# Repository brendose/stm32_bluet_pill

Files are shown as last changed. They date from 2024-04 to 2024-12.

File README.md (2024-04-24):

<h1 align="center">Welcome to Project: stm32_bluet_pill </br> (a Bluetooth OSHW design) </h1>
<div align="center">

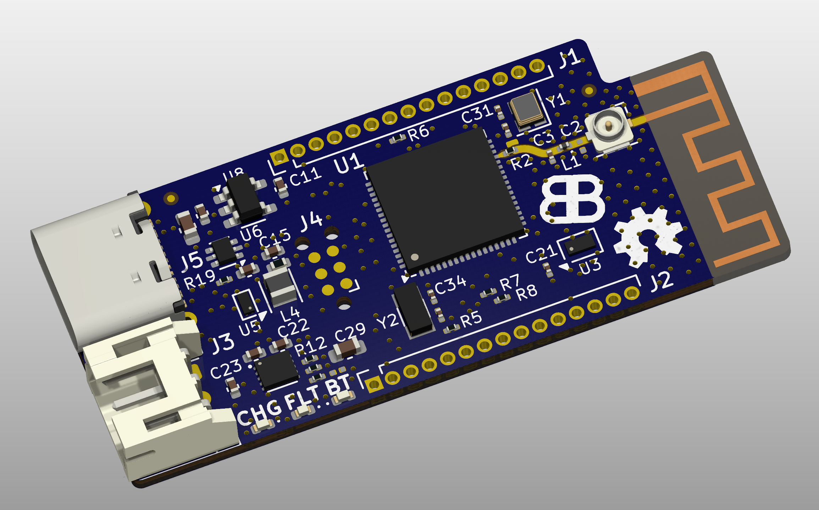
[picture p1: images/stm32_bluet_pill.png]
   

<a href="#introduction">Introduction</a> &nbsp;&bull;&nbsp;
<a href="#directory">Directory</a> &nbsp;&bull;&nbsp;
<a href="#documentation">Documentation</a> &nbsp;&bull;&nbsp;
<a href="#notes">Notes</a>
</div>

# Introduction
The <b>stm32_bluet_pill</b> project is a 'breadboardable' 1.8V IO STM32WB55 Bluetooth Module with battery charging. 
The purpose of this project is to provide a development platform for wearables. The board contains:

- ST Microelectronics STM32WB55
- 32Mbit QSPI Flash
- Texas Instruments BQ25185 battery charger
- PCB Antenna with U.FL switch connector 
- 2x 15 pin GPIO headers
- Tag-Connect JTAG connector 
- USB-C connector
- 3-Pin Battery connector
- Charge Status and Bluetooth Connection indicator LEDs

## Directory

### Projects top-level directory

    .
    ├── bom                     # stm32_blue_pill iBOM
    ├── docs                    # Documentation files (alternatively `doc`)
    ├── images                  # Images used on this GitHub page
    ├── schematics              # Schematics of the stm32_bluet_pill
    ├── step                    # 3D STEP model of the design
    ├── tapeout                 # Gerbers, Drill Drawings and other output files for PCB Fab and Assembly
    └── README.md

## Documentation

### Block Diagram
<div align="center">
  
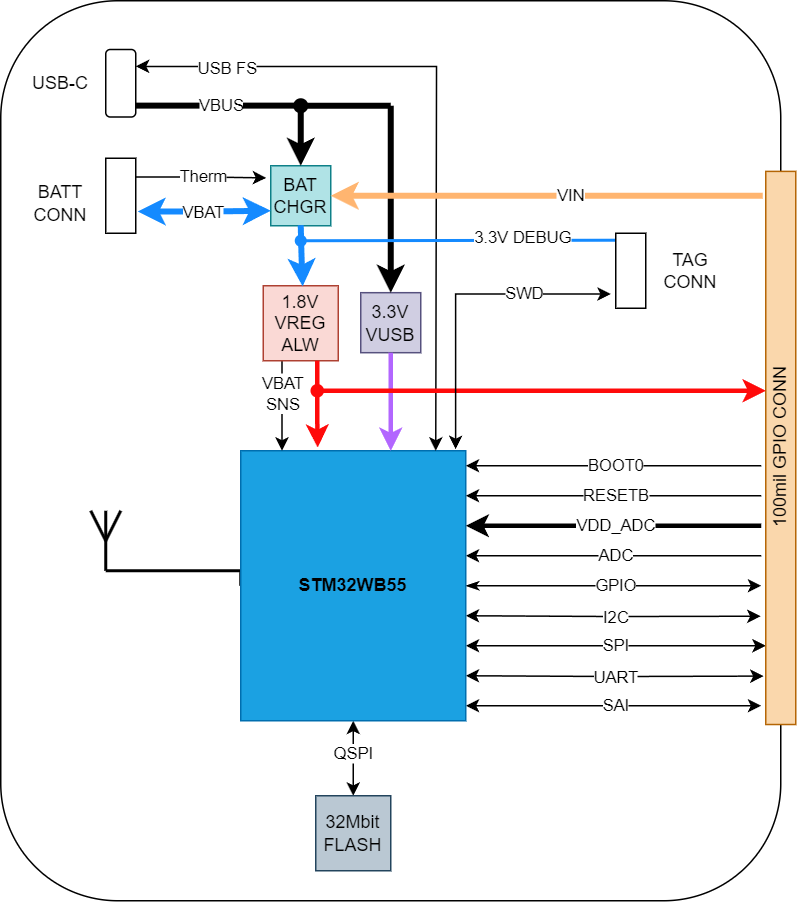
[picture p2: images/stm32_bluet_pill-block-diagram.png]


</div>

## Notes

This repository is not actively maintained, so if you spot any bugs, please <a href="https://github.com/brendose/stm32_bluet_pill/issues/new">raise an issue</a> and I will try get to it.

This is not an officially supported Google product.

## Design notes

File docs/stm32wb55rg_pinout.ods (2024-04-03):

Pin Number | Pin Name | Function | Notes
1 | VBAT
2 | PC13 | RTC_TAMP1/RTC_TS/ RTC_OUT/WKUP2
3 | PC14 | OSC32_IN
4 | PC15 | OSC32_OUT
5 | BOOT0
6 | PB8 | QUADSPI_BK1_IO1
7 | PB9 | QUADSPI_BK1_IO0
8 | NRST | RESETB
9 | PC0 | I2C3_SCL
10 | PC1 | I2C3_SDA
11 | PC2 | ADC1_IN3
12 | PC3 | ADC1_IN4
13 | VREF+
14 | VDDA
15 | PA0 | ADC1_IN5
16 | PA1 | QUADSPI_BK1_NCS
17 | PA2 | LPUART_TX
18 | PA3 | QUADSPI_CLK
19 | PA4 | VIN_SNS_ADC1_IN9
20 | PA5
21 | PA6 | QUADSPI_BK1_IO3
22 | PA7 | QUADSPI_BK1_IO2
23 | PA8 | SAI1_SCK_A
24 | PA9 | SAI1_FS_A
25 | PC4
26 | PC5
27 | PB2
28 | PB10 | LPUART_RX
29 | PB11
30 | VDDA
31 | RF1
32 | VSSRF
33 | VDDRF
34 | OSC_OUT
35 | OSC_IN
36 | AT0 | NU
37 | AT1 | NU
38 | PB0
39 | PB1
40 | PE4
41 | VFBSMPS
42 | VSSSMPS
43 | VLXSMPS
44 | VDDSMPS
45 | VDD
46 | PB12 | SPI2_NSS
47 | PB13 | SPI2_SCK
48 | PB14 | SPI2_MISO
49 | PB15 | SPI2_MOSI
50 | PC6 | SPI2_DEV_DC
51 | PA10 | SAI1_SD_A
52 | PA11 | USB_D_N
53 | PA12 | USB_D_P
54 | PA13 | SWDIO
55 | VDDUSB
56 | PA14 | SWCLK
57 | PA15
58 | PC10
59 | PC11
60 | PC12 | RTC_TAMP3/WKUP3
61 | PD0
62 | PD1
63 | PB3 | CHG_LED_GRN
64 | PB4 | CHG_LED_RED
65 | PB5 | BT_CONN_LED
66 | PB6
67 | PB7
68 | VDD

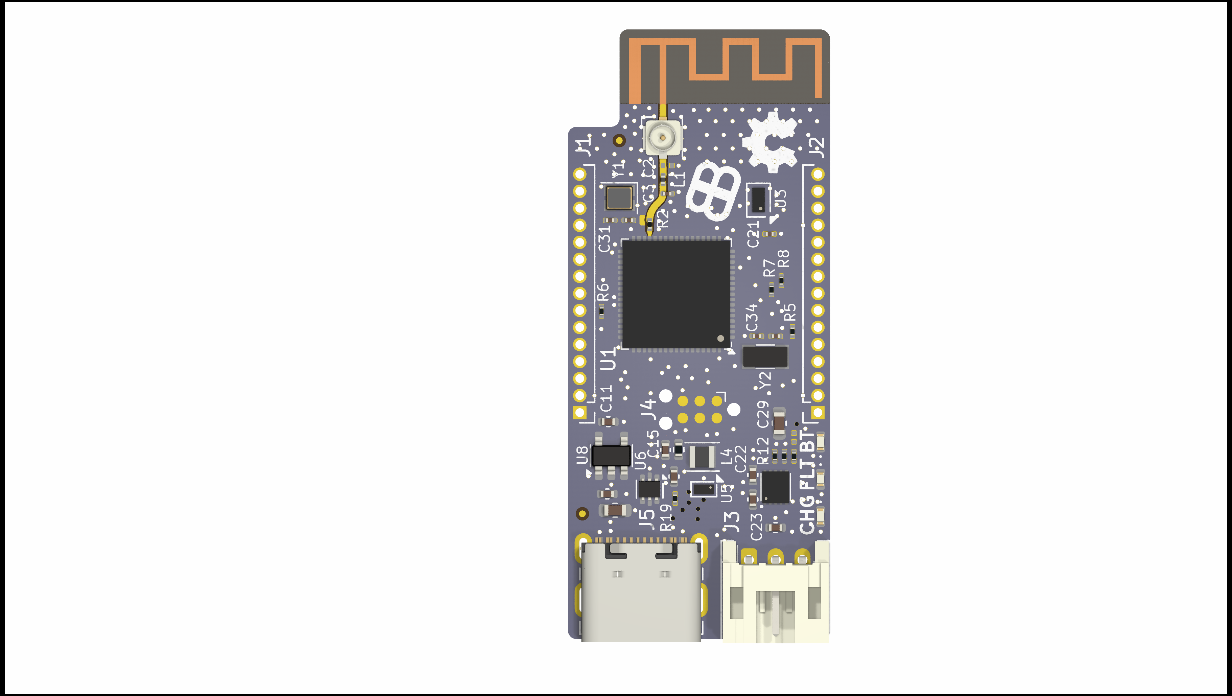
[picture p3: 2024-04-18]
images/stm32_bluet_pill_front.png

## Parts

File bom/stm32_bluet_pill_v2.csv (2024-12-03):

Reference | Value | Datasheet | Footprint | Qty | DNP
AE1 | PCB MIFA | https://www.ti.com/lit/an/swra117d/swra117d.pdf?ts=1713312109091 | RF_Antenna:Texas_SWRA117D_2.4GHz_Right | 1
C1 | 10N | ~ | Capacitor_SMD:C_0201_0603Metric | 1
C2 | 0.7P | ~ | Capacitor_SMD:C_0201_0603Metric | 1 | DNP
C3 | 0.7P | ~ | Capacitor_SMD:C_0201_0603Metric | 1
C4,C5,C6,C7,C8,C9,C10,C13,C17,C19,C21,C25,C28,C30 | 100N | ~ | Capacitor_SMD:C_0201_0603Metric | 14
C11,C12,C15 | 4.7U | ~ | Capacitor_SMD:C_0402_1005Metric | 3
C14 | 100P | ~ | Capacitor_SMD:C_0201_0603Metric | 1
C16,C22,C33 | 1.0U | ~ | -- mixed values -- | 3
C18,C34 | 7P | ~ | Capacitor_SMD:C_0201_0603Metric | 2
C20 | 2.2U 35V | ~ | Capacitor_SMD:C_0603_1608Metric | 1
C23,C29 | 1.0U 35V | ~ | -- mixed values -- | 2
C24 | 10U 10V | ~ | Capacitor_SMD:C_0402_1005Metric | 1
C26 | 10U | ~ | Capacitor_SMD:C_0402_1005Metric | 1
C27 | 1.0U 16V | ~ | Capacitor_SMD:C_0402_1005Metric | 1
C31,C32 | 8P | ~ | Capacitor_SMD:C_0201_0603Metric | 2
D1,D4,D5 | LED | ~ | Diode_SMD:D_0402_1005Metric | 3
D2 | RB081LAM-20TR | https://fscdn.rohm.com/en/products/databook/datasheet/discrete/diode/schottky_barrier/rb081lam-20tr-e.pdf | Diode_SMD:D_SOD-128 | 1
D3 | VSKY05301006-G4-08 | ~ | Diode_SMD:D_0402_1005Metric | 1
J3 | PH_S3B-PH-K | https://www.jst-mfg.com/product/pdf/eng/eZH.pdf | Connector_JST:JST_PH_S3B-PH-K_1x03_P2.00mm_Horizontal | 1
J5 | DX07S016JA1R1500 |  | Connector_USB:USB_C_Receptacle_JAE_DX07S016JA1R1500 | 1
L1 | 2.2N | ~ | Diode_SMD:D_0201_0603Metric | 1
L4 | 2.2U | ~ | Inductor_SMD:L_Murata_DFE201610P | 1
Q1,Q2 | DMG1012T | https://www.diodes.com/assets/Datasheets/ds31783.pdf | Package_TO_SOT_SMD:SOT-523 | 2
R1,R19,R25 | 100K | ~ | Resistor_SMD:R_0201_0603Metric | 3
R2,R10,R14,R23,R26 | 0R | ~ | -- mixed values -- | 5
R3,R22 | 470R | ~ | Resistor_SMD:R_0201_0603Metric | 2
R4,R5,R17 | 10K | ~ | Resistor_SMD:R_0201_0603Metric | 3
R6,R9,R13,R15 | 0R | ~ | -- mixed values -- | 4 | DNP
R7,R8 | 680R | ~ | Resistor_SMD:R_0201_0603Metric | 2
R11 | 2.4K | ~ | Resistor_SMD:R_0201_0603Metric | 1
R12 | 600R | ~ | Resistor_SMD:R_0201_0603Metric | 1
R16 | 2.2K | ~ | Resistor_SMD:R_0201_0603Metric | 1
R18,R24 | 1K | ~ | Resistor_SMD:R_0201_0603Metric | 2
R20,R21 | 5.1K | ~ | Resistor_SMD:R_0201_0603Metric | 2
TP1 | MS-156C3 | https://www.hirose.com/en/product/document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 | Connector_Coaxial:CoaxialSwitch_Hirose_MS-156C3_Horizontal | 1
U1 | STM32WB55RGVx | https://www.st.com/resource/en/datasheet/stm32wb55rg.pdf | Package_DFN_QFN:QFN-68-1EP_8x8mm_P0.4mm_EP6.4x6.4mm | 1
U3 | AT25SL321-U | https://www.adestotech.com/wp-content/uploads/AT25SL321_112.pdf | Package_CSP:WLCSP-8_1.551x2.284mm_P0.5mm | 1
U4 | BQ25185 | https://www.ti.com/lit/ds/symlink/bq25185.pdf?ts=1709530829257 | user_wson:Texas_DLH_WSON-10 | 1
U5 | TPS62746 | https://www.ti.com/lit/ds/symlink/tps62746.pdf?ts=1709244779633 | Package_BGA:Texas_DSBGA-8_0.705x1.468mm_Layout2x4_P0.4mm | 1
U6 | USBLC6-2P6 | https://www.st.com/resource/en/datasheet/usblc6-2.pdf | Package_TO_SOT_SMD:SOT-666 | 1
U8 | TPS7A0533PDBV | https://www.ti.com/lit/ds/symlink/tps7a05.pdf | Package_TO_SOT_SMD:SOT-23-5 | 1
Y1 | ECS-320-8-37CKM | https://ecsxtal.com/store/pdf/ecx-1637.pdf | Crystal:Crystal_SMD_2016-4Pin_2.0x1.6mm | 1
Y2 | SC32S-7PF20PPM | ~ | Crystal:Crystal_SMD_3215-2Pin_3.2x1.5mm | 1

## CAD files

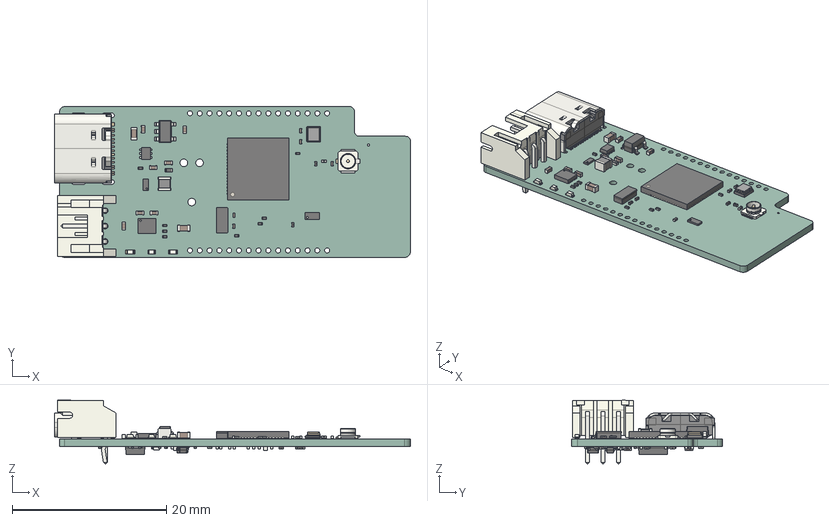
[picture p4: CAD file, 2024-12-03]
step/stm32_bluet_pill.step
46.1 x 19.6 x 8.25 mm
R_0201_0603Metric x 20
C_0201_0603Metric x 23
C_0402_1005Metric x 9
CQ assembly x 3
C_0603_1608Metric x 2
LED_0402_1005Metric x 3
L_0201_0603Metric
L_0805_2012Metric
R_0402_1005Metric
JST_S3B_PH_K
USB_C_Receptacle_16P_TopMnt_Horizontal_GCT_USB4105-xx-A
Crystal_SMD_2520-4Pin_2.5x2.0mm
U.FL_Hirose_U.FL-R-SMT-1_Vertical
MicroCrystal_CC7V_T1A
SOT_666
SOT_23_5
QFN_68_1EP_8x8mm_P04mm_EP52x52mm
SOT_323_SC_70 x 2
R_0603_1608Metric
D_SOD-128
stm32_bluet_pill_PCB

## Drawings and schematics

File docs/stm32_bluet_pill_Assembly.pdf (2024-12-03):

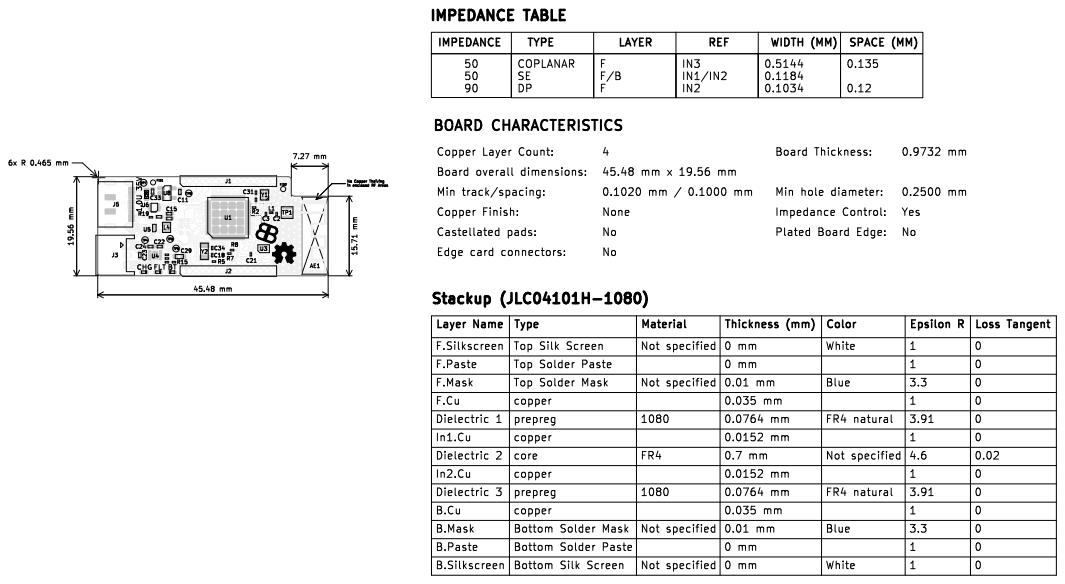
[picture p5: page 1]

Top Solder Mask F.Paste BOARD CHARACTERISTICS

1080 Copper Layer Count: Bottom Silk Screen

Layer Name | pads: F.Cu | | | | | | | 0 Top Solder Paste Castellated
1 FR4 F.Mask 3.3 White | | 0 Edge card connectors: 0

copper | | 0 mm (mm) 0.035 mm | | 1 White 3.91 Not specified B.Mask 3.91 | | 0 Thickness 0
1 | Top Silk copper F.Silkscreen | Screen | | | | | 0.01 mm | | 1 Dielectric

Not specified | 0.0764 mm | | | | 0.02 B.Paste

core | | | | 4.6

prepreg | | | | | 0
copper | | 0.035 mm | | | | 0

Paste | | 0 mm | | | | 0 Bottom Solder

B.Silkscreen

Id: 1/1 Title: stm32_bluet_pill File: stm32_bluet_pill.kicad_pcb Sheet: Black And White TOP Brendan Bleker Designed by:

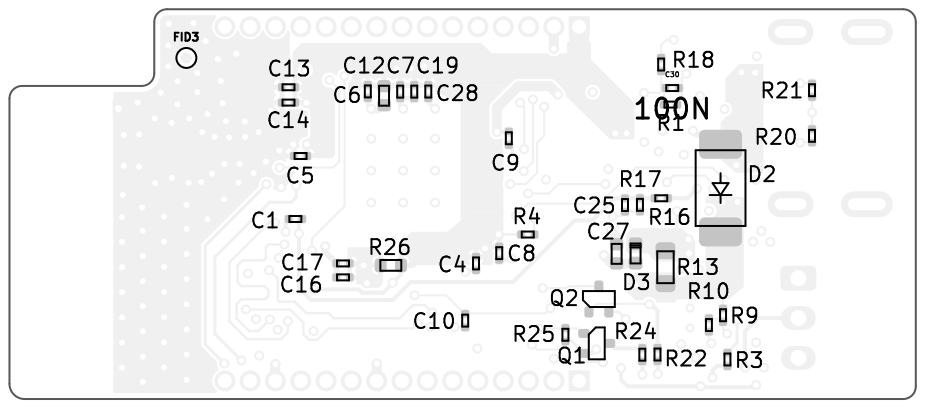
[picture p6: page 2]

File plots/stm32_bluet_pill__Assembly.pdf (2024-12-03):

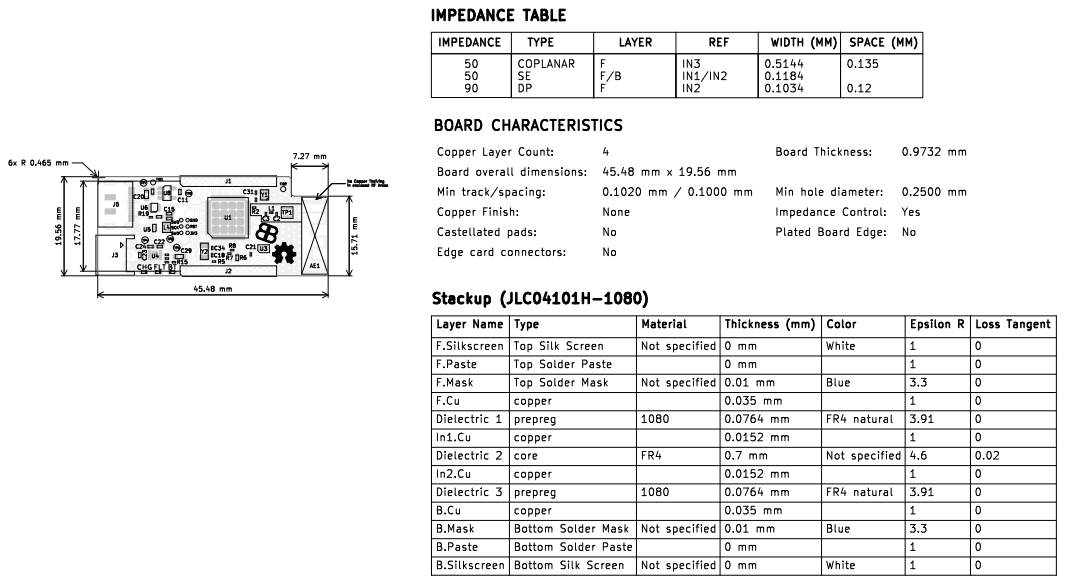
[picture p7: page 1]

Top Solder Mask F.Paste BOARD CHARACTERISTICS

1080 Copper Layer Count: Bottom Silk Screen

Layer Name | pads: F.Cu | | | | | 0 Top Solder Paste Castellated
1 FR4 F.Mask 3.3 White | 0 Edge card connectors: 0

copper | | 0 mm (mm) 0.035 mm | | 1 White 3.91 Not specified B.Mask 3.91 | | 0 Thickness 0
1 | Top Silk copper F.Silkscreen Screen | | | | 0.01 mm | | 1 Dielectric

prepreg | Not specified | 0.0764 mm | | | 0.02 B.Paste

core | | | | 4.6

In2.Cu | | | 0.0152 mm
Dielectric 3 | prepreg | | | | | | 0

copper | | 0.035 mm | | | | 0
Bottom Solder Mask | Not specified | 0.01 mm | | | | 0
Paste | | 0 mm | | 1 | 0 Bottom Solder

B.Silkscreen

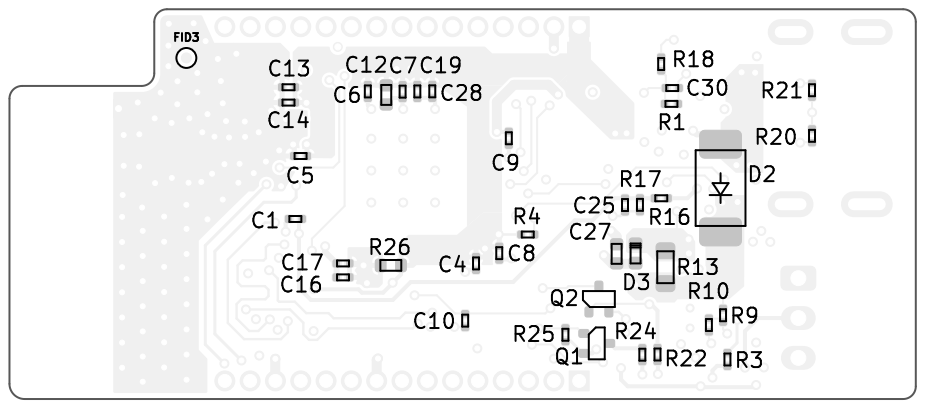
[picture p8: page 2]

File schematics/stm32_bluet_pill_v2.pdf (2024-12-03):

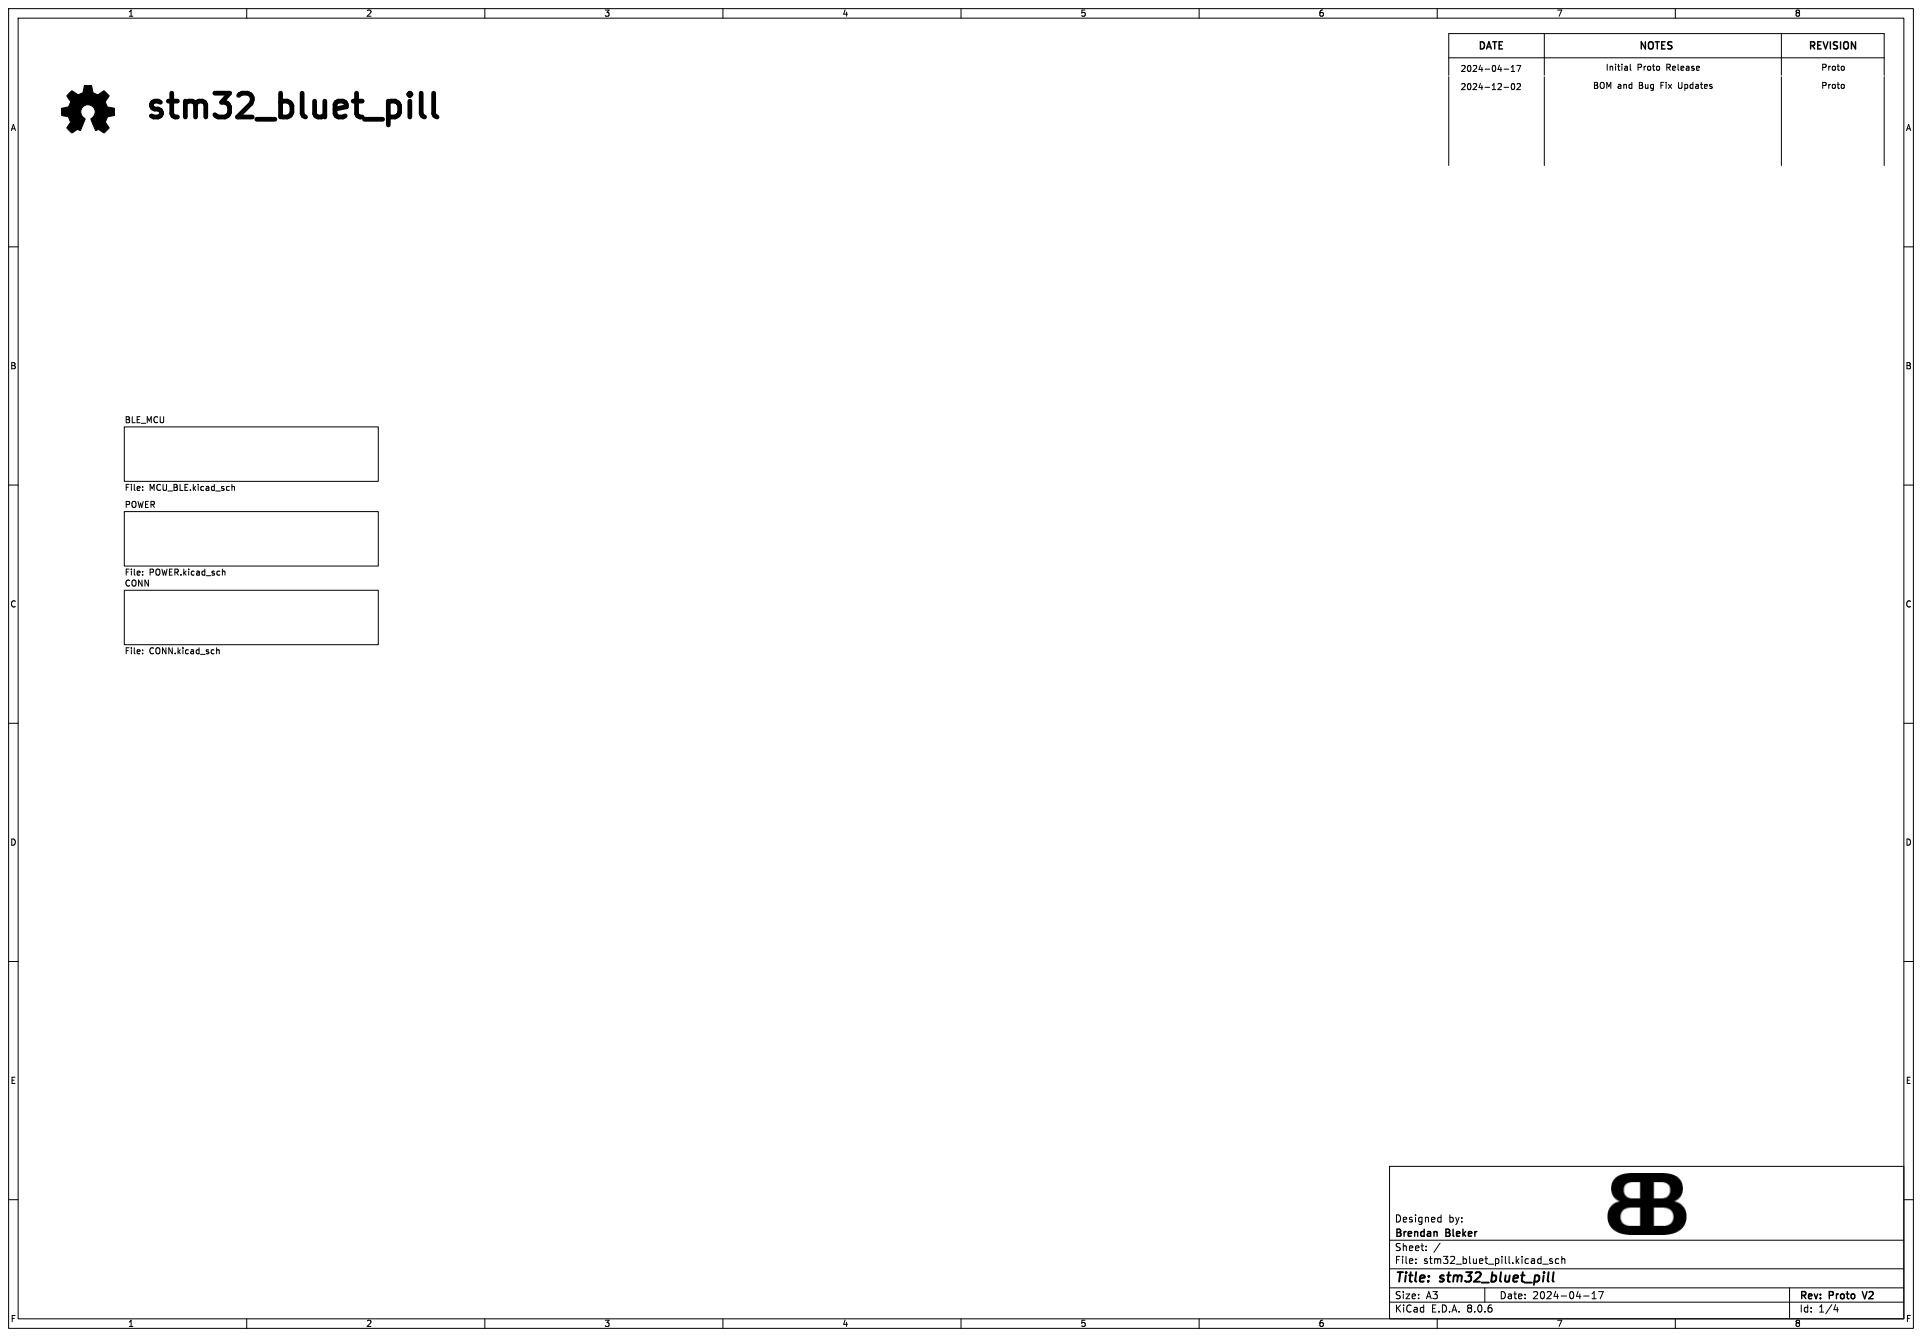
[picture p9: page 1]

Initial Proto Release | Proto BOM and Bug Fix Updates Proto

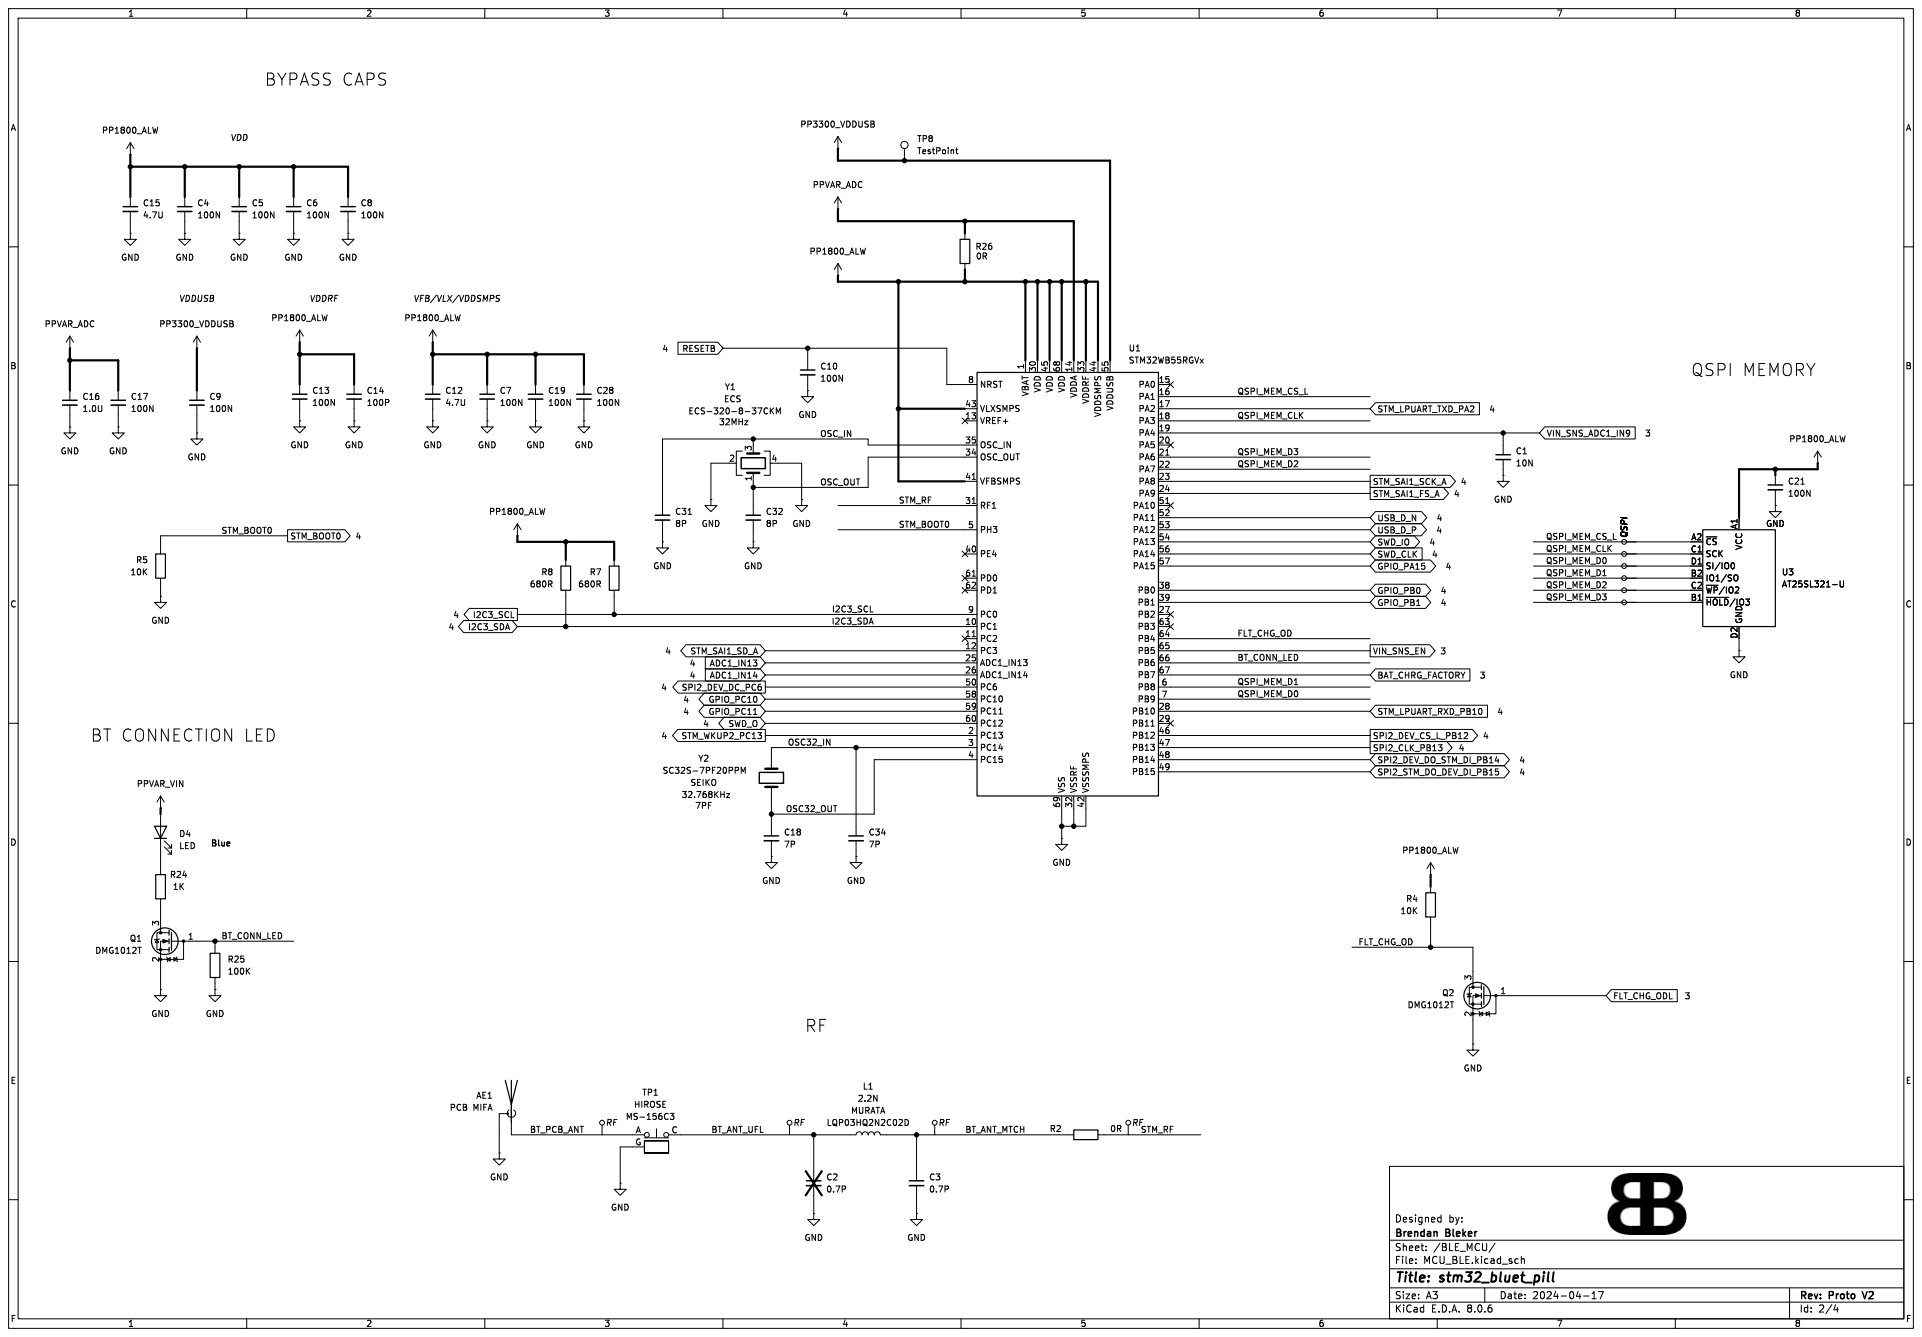
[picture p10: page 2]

VFB/VLX/VDDSMPS BYPASS CAPS

1 PC1 10 PC2 11 PC3 12 VREF+ 13 VDDA 14 PA0 15 PA1 16 PA2 17 PA3 18 PA4 19 PC13 2 PA5 20 PA6 21 PA7 22 PA8 23 PA9 24 ADC1_IN13 25 ADC1_IN14 26 PB2 27 PB10 28 PB11 29 PC14 3 VDD 30 RF1 31 VSSRF 32 VDDRF 33 OSC_OUT 34 OSC_IN 35 PB0 38 PB1 39 PC15 4 PE4 40 VFBSMPS 41 VSSSMPS 42 VLXSMPS 43 VDDSMPS 44 VDD 45 PB12 46 PB13 47 PB14 48 PB15 49 PH3 5 PC6 50 PA10 51 PA11 52 PA12 53 PA13 54 VDDUSB 55 PA14 56 PA15 57 PC10 58 PC11 59 PB8 6 PC12 60 PD0 61 PD1 62 PB3 63 PB4 64 PB5 65 PB6 66 PB7 67 VDD 68 VSS 69 PB9 7 NRST 8 PC0 9 U1STM32WB55RGVx R26

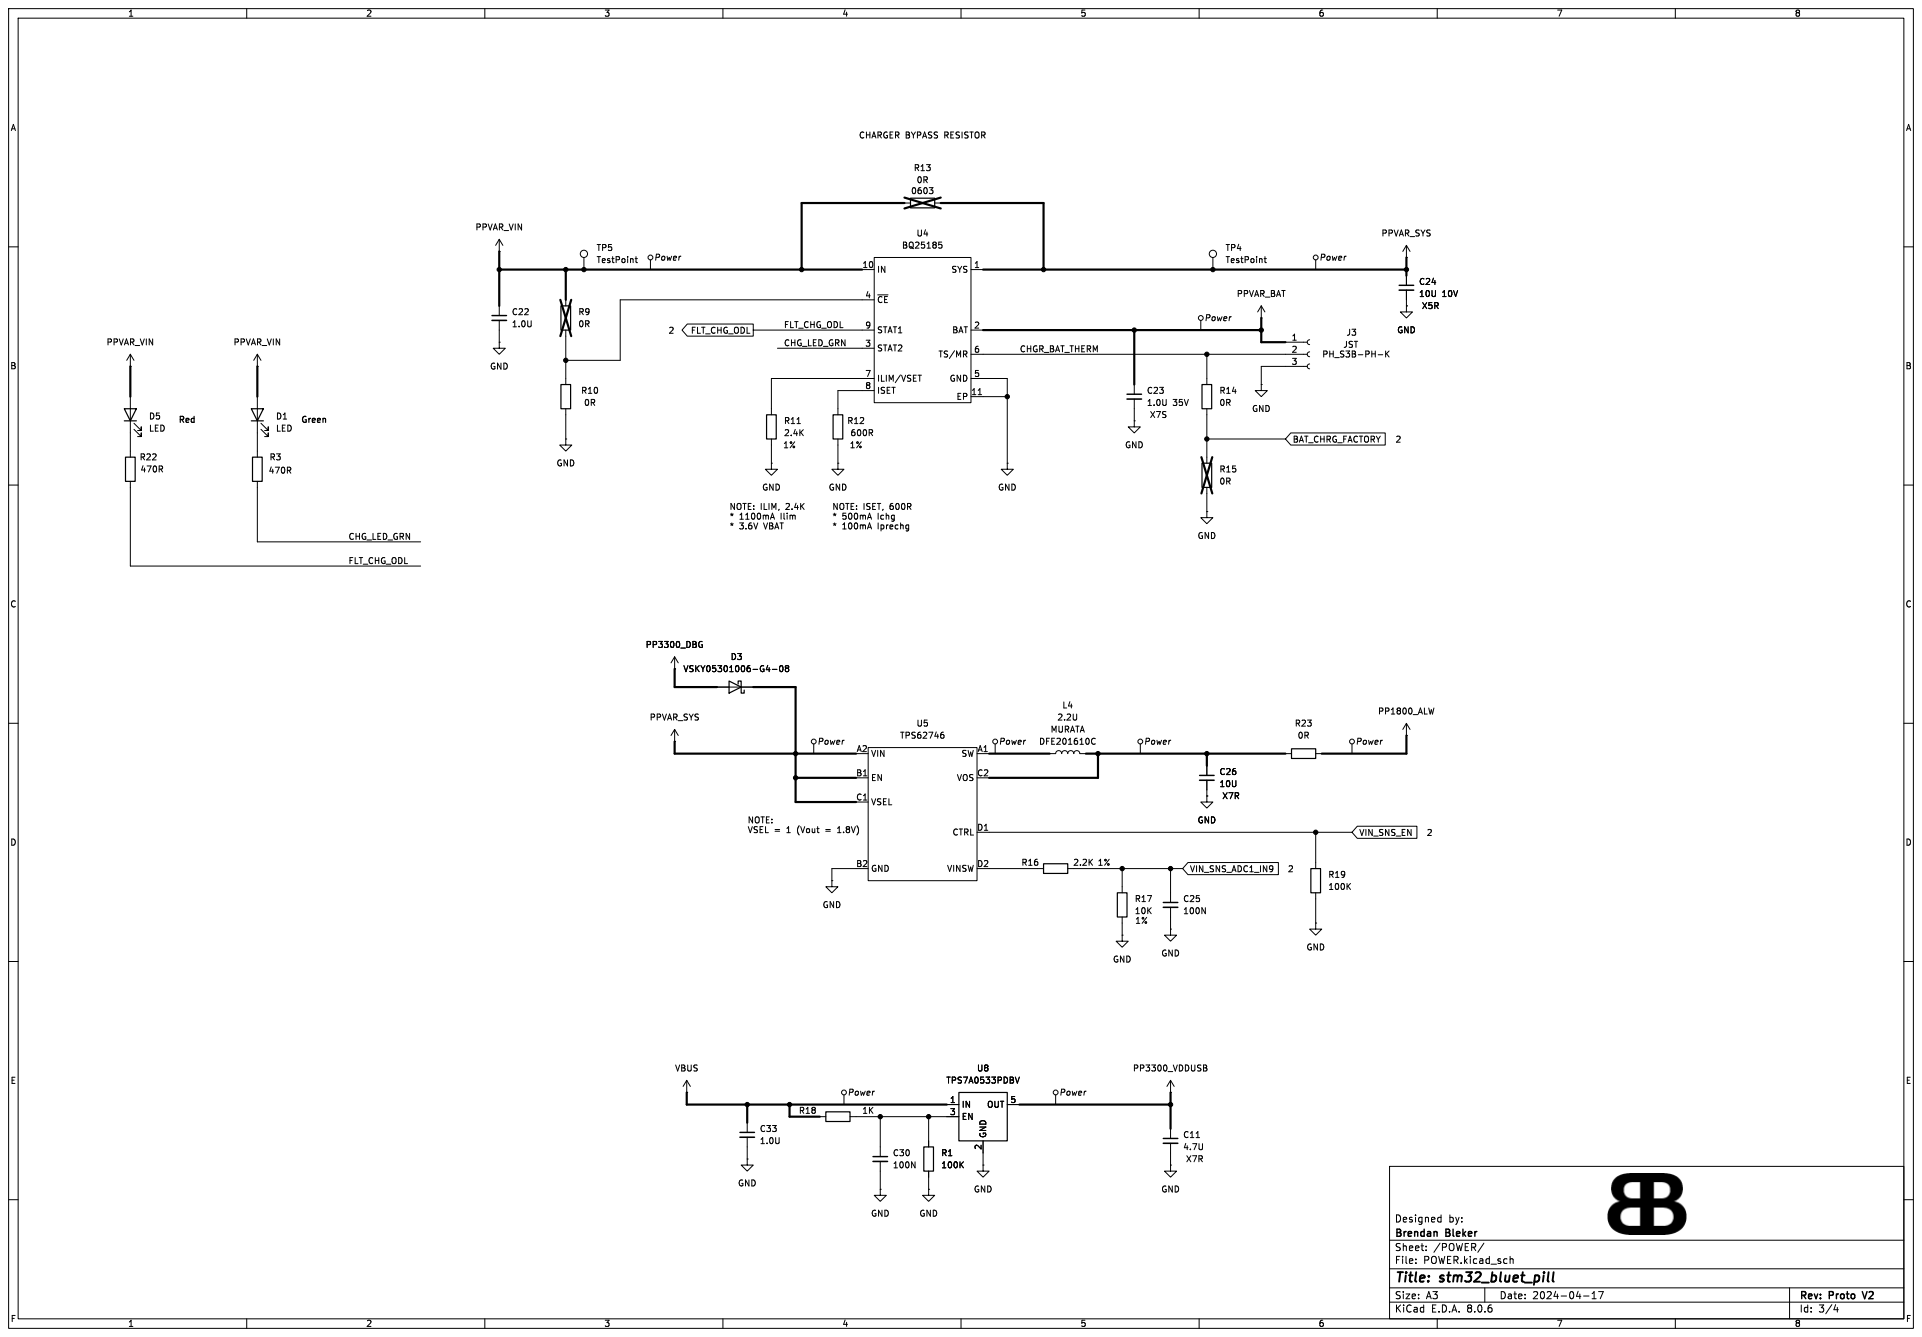
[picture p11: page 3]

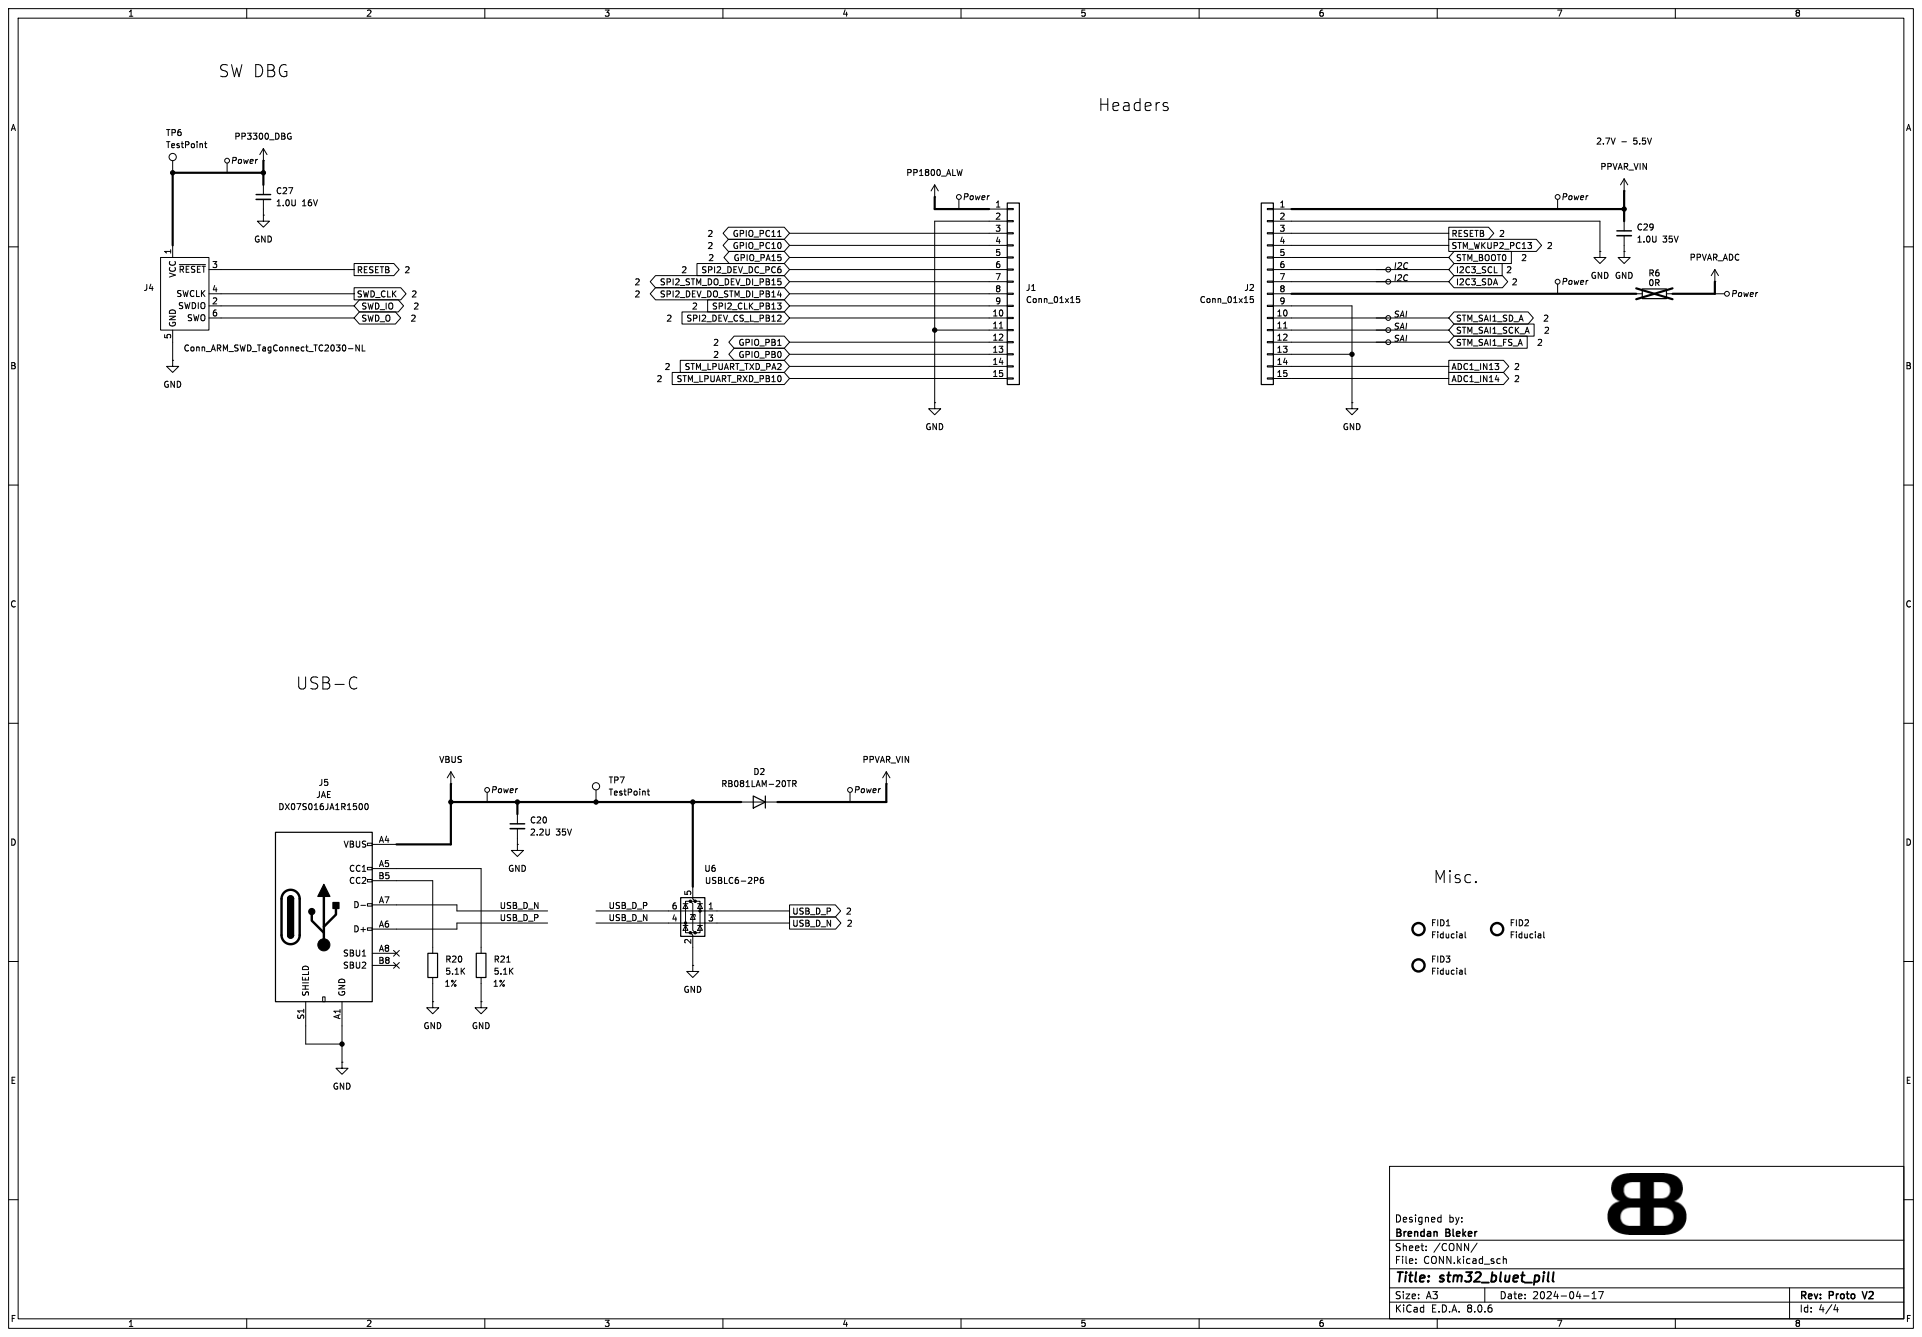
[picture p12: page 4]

1 SWDIO 2 ~{RESET}3 SWCLK 4 GND
2.2U 35V GNDVCC

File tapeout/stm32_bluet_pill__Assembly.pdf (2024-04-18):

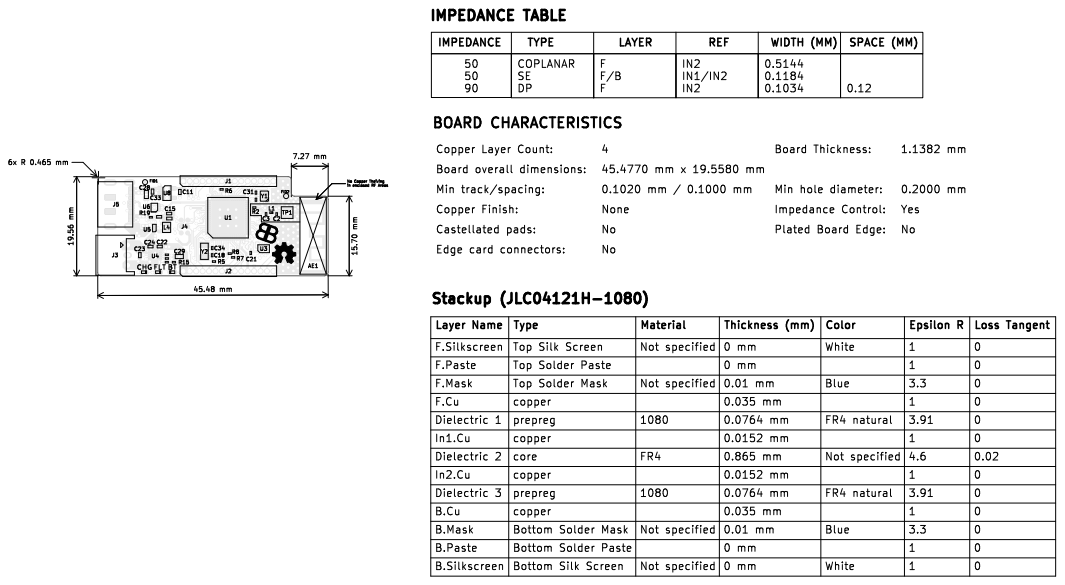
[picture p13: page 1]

IMPEDANCE TABLE
prepreg Min track/spacing: F.Cu

Layer Name | | | | | | | | | 1 No
0.0152 mm 0.01 mm | 3.91 Material | Loss Tangent 0

F.Paste | | | | | FR4 | | | Epsilon R

0.01 mm 0.035 mm | White | | 0

copper | | 0 mm 0.0764 mm

1 In1.Cu | | | Not specified | | | 1 Blue Dielectric | 0 Bottom Solder Mask 0

In2.Cu | | | | 0.0152 mm | Not specified | 3.91 B.Silkscreen | 0 White 0 B.Mask

core | | | 0.865 mm | | 4.6

0 mm | | | 0
0 mm | | | | 0

Id: 1/1 Title: stm32_bluet_pill File: stm32_bluet_pill.kicad_pcb Sheet: Brendan Bleker Designed by:

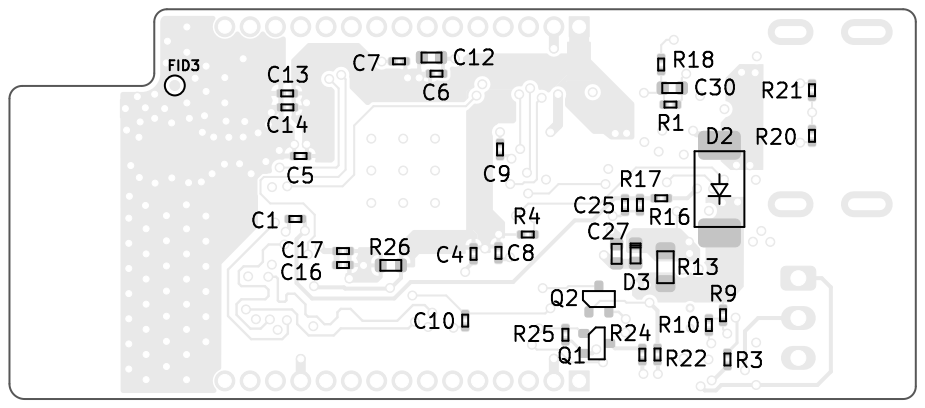
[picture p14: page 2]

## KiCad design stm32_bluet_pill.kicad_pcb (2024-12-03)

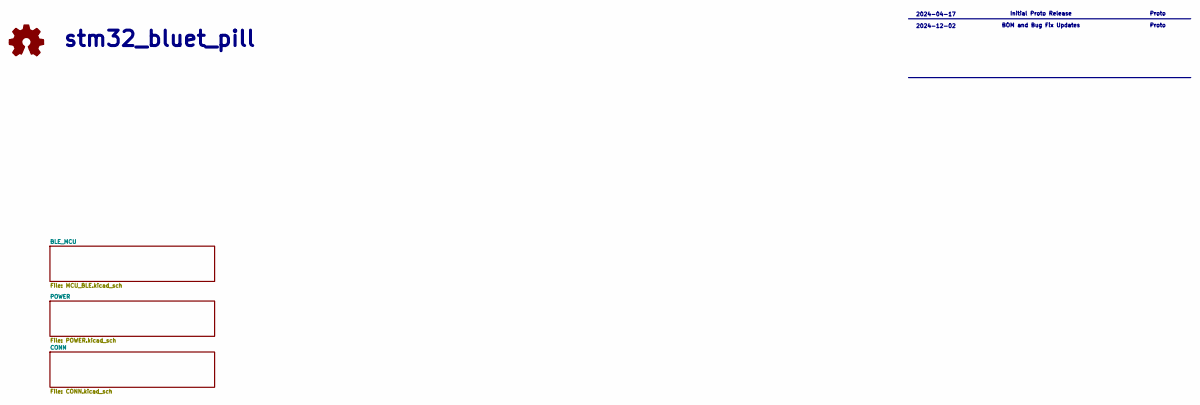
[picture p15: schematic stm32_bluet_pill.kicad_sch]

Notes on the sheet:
Proto
2024-04-17
${TITLE}
Initial Proto Release
BOM and Bug Fix Updates
2024-12-02

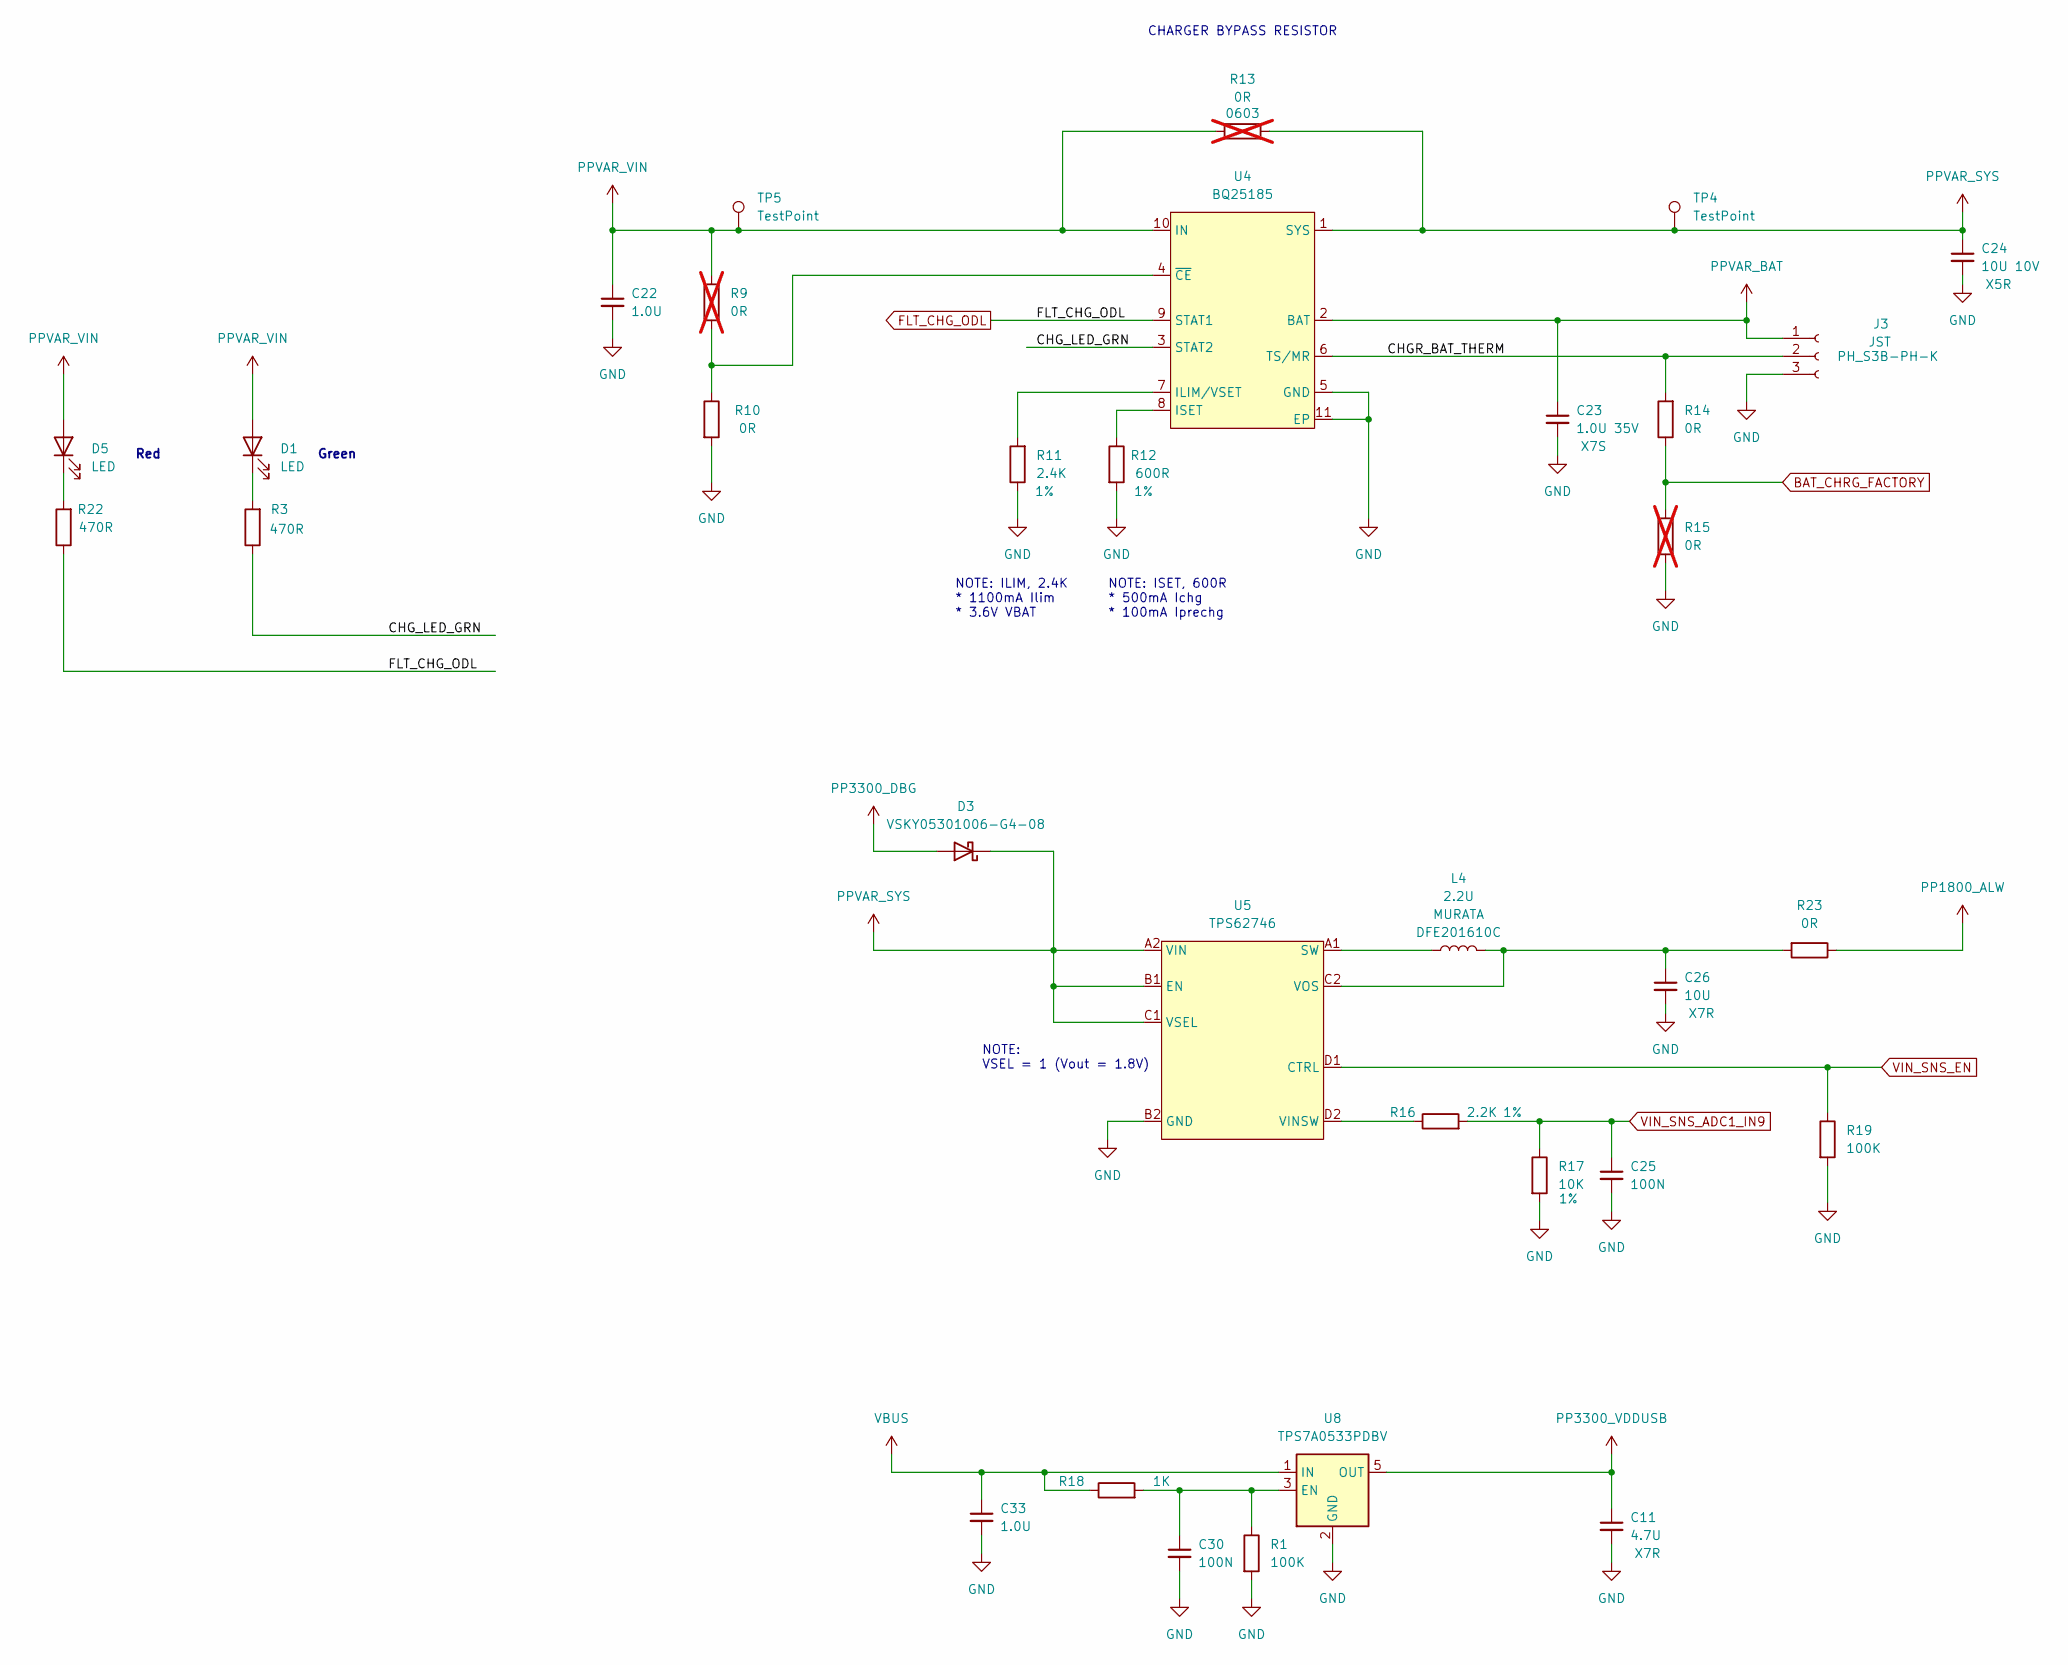
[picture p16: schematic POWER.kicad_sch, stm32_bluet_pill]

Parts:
C11: 4.7U; C_0402_1005Metric; MFG_PN GRM155R60J106ME11
C22, C33: 1.0U; C_0402_1005Metric
C23: 1.0U 35V; C_0402_1005Metric; MFR_PN C1005JB1V105K050BC
C24: 10U 10V; C_0402_1005Metric; MFR_PN CL05A106MP8NUB8
C25, C30: 100N; C_0201_0603Metric
C26: 10U; C_0402_1005Metric; MFG_PN GRM155R60J106ME11
D1, D5: LED; D_0402_1005Metric
D3: VSKY05301006-G4-08; D_0402_1005Metric
J3: PH_S3B-PH-K; JST_PH_S3B-PH-K_1x03_P2.00mm_Horizontal; MFG_PN PH_S3B-PH-K
L4: 2.2U; L_Murata_DFE201610P; MFG_PN DFE201610C
R1, R19: 100K; R_0201_0603Metric
R3, R22: 470R; R_0201_0603Metric
R9, R15: 0R; R_0201_0603Metric; not fitted
R10, R14: 0R; R_0201_0603Metric
R11: 2.4K; R_0201_0603Metric
R12: 600R; R_0201_0603Metric
R13: 0R; R_0603_1608Metric; not fitted
R16: 2.2K; R_0201_0603Metric
R17: 10K; R_0201_0603Metric
R18: 1K; R_0201_0603Metric
R23: 0R; R_0402_1005Metric
TP4, TP5: TestPoint; TestPoint_Pad_D1.0mm
U4: BQ25185; Texas_DLH_WSON-10
U5: TPS62746; Texas_DSBGA-8_0.705x1.468mm_Layout2x4_P0.4mm
U8: TPS7A0533PDBV; SOT-23-5

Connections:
/POWER/CHGR_BAT_THERM: J3.2, R14.2, U4.6 (TS/MR)
/POWER/CHG_LED_GRN: R3.1, U4.3 (STAT2)
BAT_CHRG_FACTORY: R14.1, R15.2; also elsewhere on the board
FLT_CHG_ODL: R22.1, U4.9 (STAT1); also elsewhere on the board
GND: C11.2, C22.2, C23.2, C24.2, C25.2, C26.2, C30.2, C33.2, J3.3, R1.2, R10.2, R11.1, R12.2, R15.1, R17.2, R19.2, U4.5 (GND), U4.11 (EP), U5.B2 (GND), U8.2 (GND); also elsewhere on the board
unnamed: D1.1 (K), R3.2
unnamed: D5.1 (K), R22.2
unnamed: R11.2, U4.7 (ILIM/VSET)
unnamed: R12.1, U4.8 (ISET)
unnamed: R9.1, R10.1, U4.4 (~CE)
unnamed: L4.1, U5.A1 (SW)
unnamed: R16.1, U5.D2 (VINSW)
unnamed: C26.1, L4.2, R23.2, U5.C2 (VOS)
unnamed: C30.1, R1.1, R18.2, U8.3 (EN)
PP1800_ALW: R23.1; also elsewhere on the board
PP3300_DBG: D3.2 (A); also elsewhere on the board
PP3300_VDDUSB: C11.1, U8.5 (OUT); also elsewhere on the board
PPVAR_BAT: C23.1, J3.1, U4.2 (BAT)
PPVAR_SYS: C24.1, D3.1 (K), R13.1, TP4.1, U4.1 (SYS), U5.A2 (VIN), U5.B1 (EN), U5.C1 (VSEL)
PPVAR_VIN: C22.1, D1.2 (A), D5.2 (A), R9.2, R13.2, TP5.1, U4.10 (IN); also elsewhere on the board
VBUS: C33.1, R18.1, U8.1 (IN); also elsewhere on the board
VIN_SNS_ADC1_IN9: C25.1, R16.2, R17.1; also elsewhere on the board
VIN_SNS_EN: R19.1, U5.D1 (CTRL); also elsewhere on the board

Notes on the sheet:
CHARGER BYPASS RESISTOR
NOTE: ILIM, 2.4K * 1100mA Ilim * 3.6V VBAT
NOTE: VSEL = 1 (Vout = 1.8V)
Red
NOTE: ISET, 600R * 500mA Ichg * 100mA Iprechg
Green

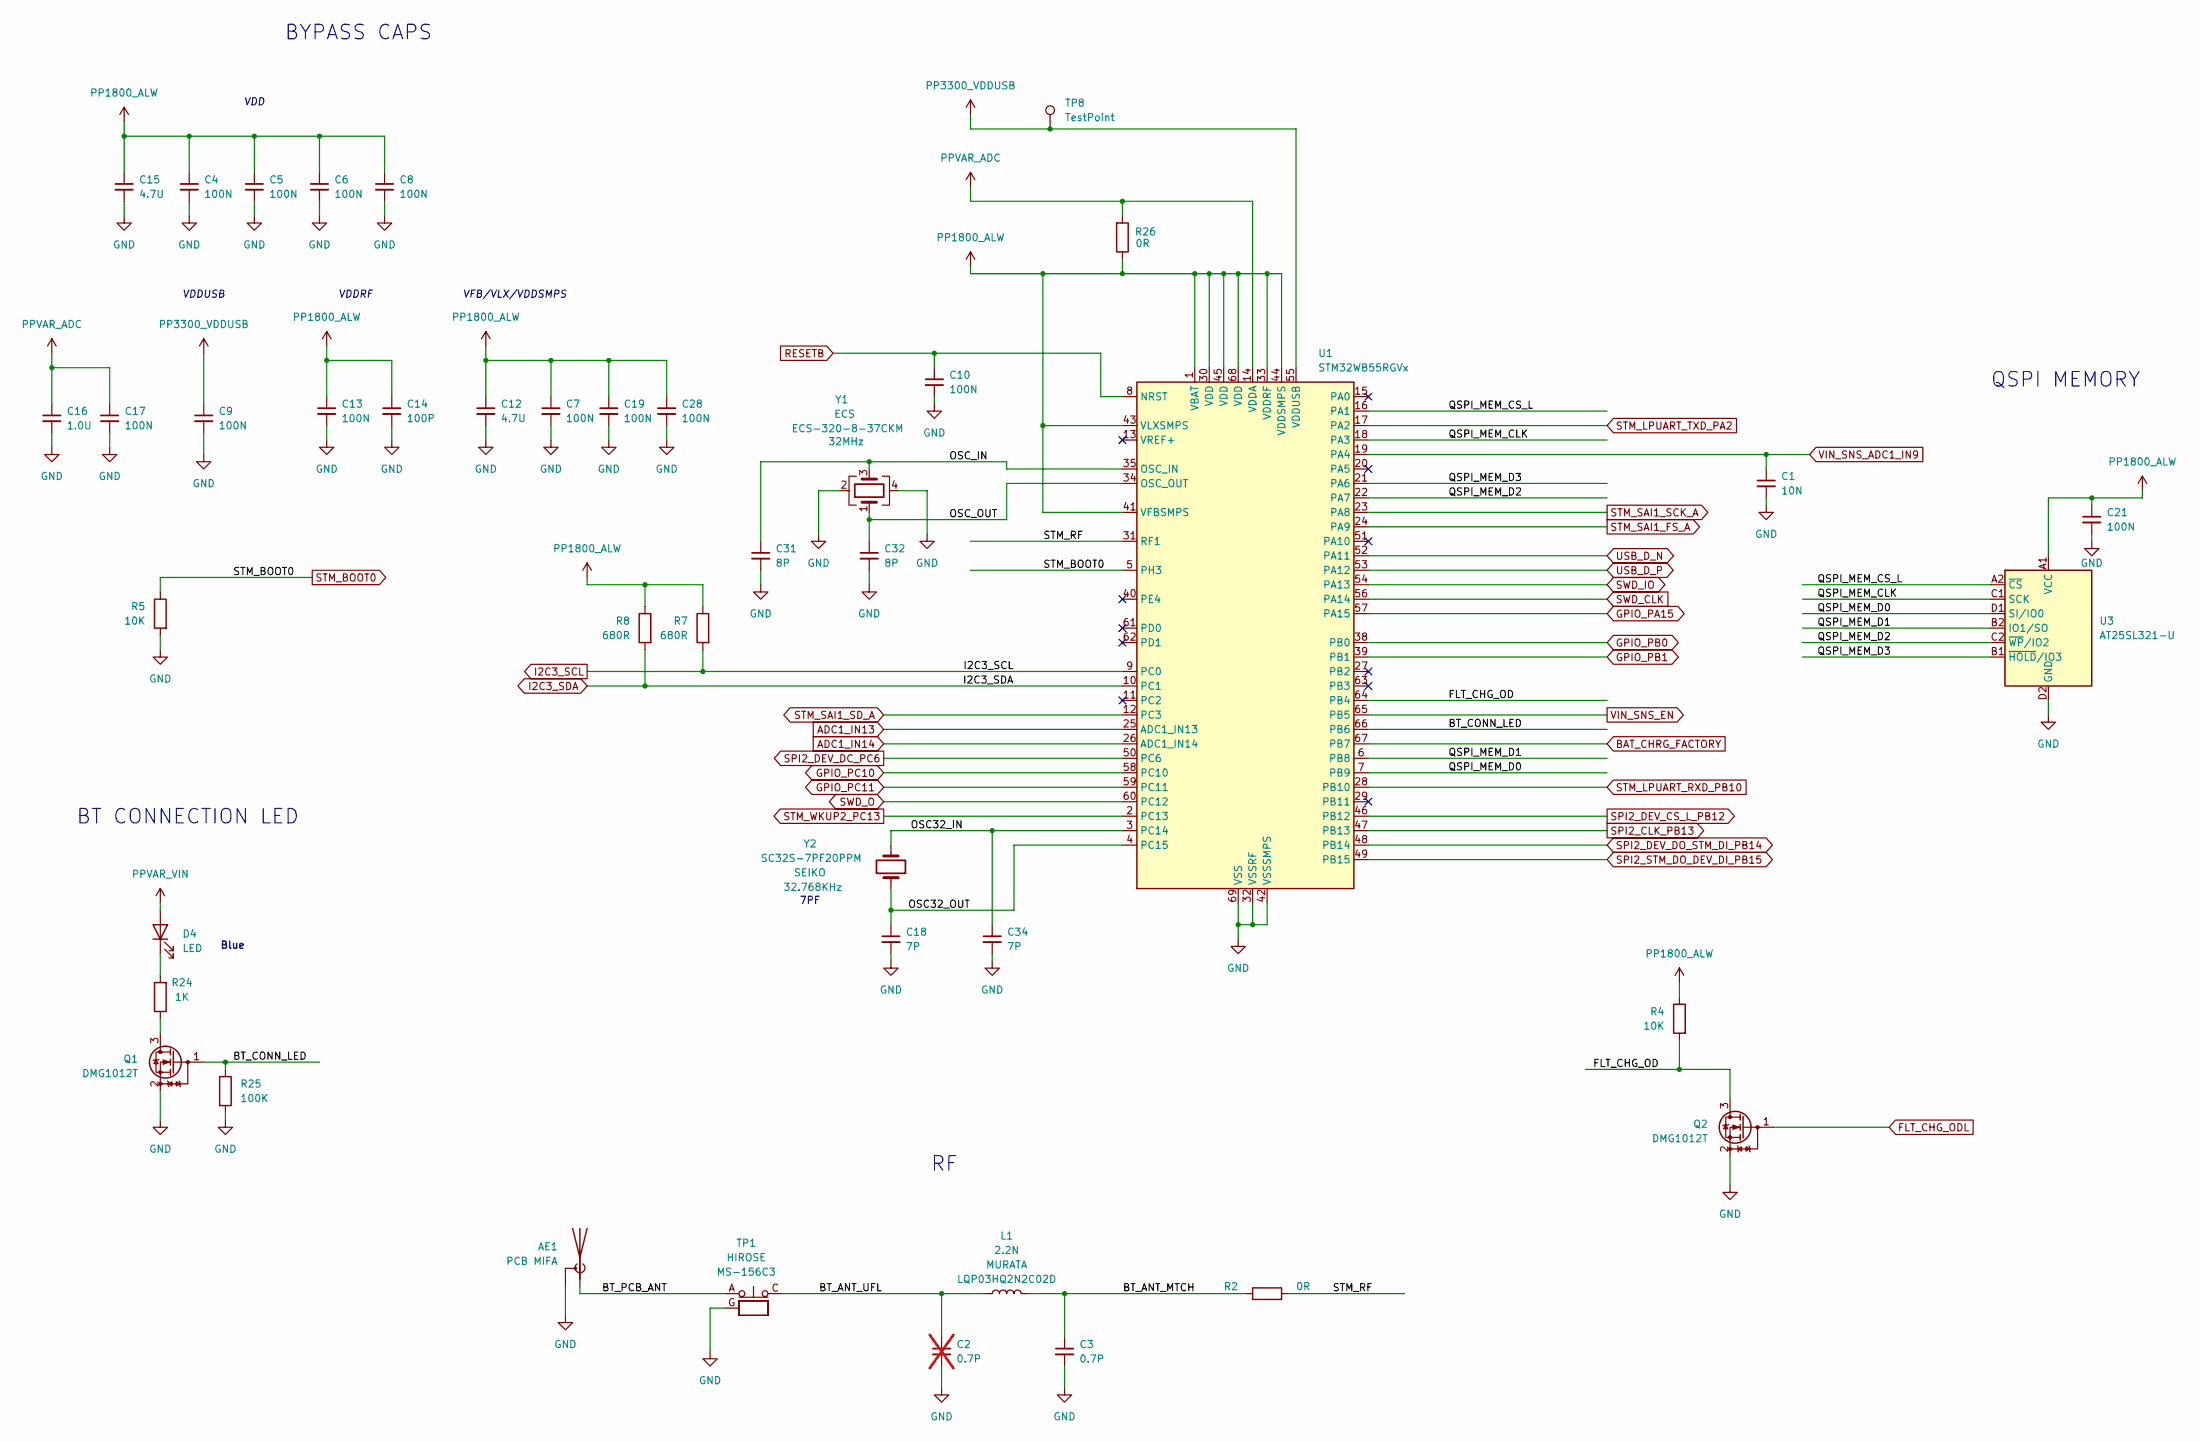
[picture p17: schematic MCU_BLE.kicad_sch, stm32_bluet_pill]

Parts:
AE1: PCB MIFA; Texas_SWRA117D_2.4GHz_Right
C1: 10N; C_0201_0603Metric
C2: 0.7P; C_0201_0603Metric; not fitted
C3: 0.7P; C_0201_0603Metric
C4, C5, C6, C7, C8, C9, C10, C13, C17, C19, C21, C28: 100N; C_0201_0603Metric
C12, C15: 4.7U; C_0402_1005Metric
C14: 100P; C_0201_0603Metric
C16: 1.0U; C_0201_0603Metric
C18, C34: 7P; C_0201_0603Metric
C31, C32: 8P; C_0201_0603Metric
D4: LED; D_0402_1005Metric
L1: 2.2N; D_0201_0603Metric; MFG_PN LQP03HQ2N2C02D
Q1, Q2: DMG1012T; SOT-523
R2: 0R; R_0201_0603Metric
R4, R5: 10K; R_0201_0603Metric
R7, R8: 680R; R_0201_0603Metric
R24: 1K; R_0201_0603Metric
R25: 100K; R_0201_0603Metric
R26: 0R; R_0402_1005Metric
TP1: MS-156C3; CoaxialSwitch_Hirose_MS-156C3_Horizontal; MFG_PN MS-156C3
TP8: TestPoint; TestPoint_Pad_D1.0mm
U1: STM32WB55RGVx; QFN-68-1EP_8x8mm_P0.4mm_EP6.4x6.4mm
U3: AT25SL321-U; WLCSP-8_1.551x2.284mm_P0.5mm
Y1: ECS-320-8-37CKM; Crystal_SMD_2016-4Pin_2.0x1.6mm; MFG_PN ECS-320-8-37CKM
Y2: SC32S-7PF20PPM; Crystal_SMD_3215-2Pin_3.2x1.5mm; MFG_PN SC32S-7PF20PPM

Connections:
/BLE_MCU/BT_ANT_MTCH: C3.1, L1.2, R2.1
/BLE_MCU/BT_ANT_UFL: C2.1, L1.1, TP1.C
/BLE_MCU/BT_CONN_LED: Q1.1 (G), R25.1, U1.66 (PB6)
/BLE_MCU/BT_PCB_ANT: AE1.1 (A), TP1.A
/BLE_MCU/FLT_CHG_OD: Q2.3 (D), R4.2, U1.64 (PB4)
/BLE_MCU/OSC32_IN: C34.1, U1.3 (PC14), Y2.2
/BLE_MCU/OSC32_OUT: C18.1, U1.4 (PC15), Y2.1
/BLE_MCU/OSC_IN: C31.1, U1.35 (OSC_IN), Y1.3
/BLE_MCU/OSC_OUT: C32.1, U1.34 (OSC_OUT), Y1.1
/BLE_MCU/QSPI_MEM_CLK: U1.18 (PA3), U3.C1 (SCK)
/BLE_MCU/QSPI_MEM_CS_L: U1.16 (PA1), U3.A2 (~CS)
/BLE_MCU/QSPI_MEM_D0: U1.7 (PB9), U3.D1 (SI/IO0)
/BLE_MCU/QSPI_MEM_D1: U1.6 (PB8), U3.B2 (IO1/SO)
/BLE_MCU/QSPI_MEM_D2: U1.22 (PA7), U3.C2 (~WP/IO2)
/BLE_MCU/QSPI_MEM_D3: U1.21 (PA6), U3.B1 (~HOLD/IO3)
/BLE_MCU/STM_RF: R2.2, U1.31 (RF1)
ADC1_IN13: U1.25 (ADC1_IN13); also elsewhere on the board
ADC1_IN14: U1.26 (ADC1_IN14); also elsewhere on the board
BAT_CHRG_FACTORY: U1.67 (PB7); also elsewhere on the board
FLT_CHG_ODL: Q2.1 (G); also elsewhere on the board
GND: AE1.2 (Shield), C1.2, C2.2, C3.2, C4.2, C5.2, C6.2, C7.2, C8.2, C9.2, C10.2, C12.2, C13.2, C14.2, C15.2, C16.2, C17.2, C18.2, C19.2, C21.2, C28.2, C31.2, C32.2, C34.2, Q1.2 (S), Q2.2 (S), R5.2, R25.2, TP1.G, U1.32 (VSSRF), U1.42 (VSSSMPS), U1.69 (VSS), U3.D2 (GND), Y1.2, Y1.4; also elsewhere on the board
GPIO_PA15: U1.57 (PA15); also elsewhere on the board
GPIO_PB0: U1.38 (PB0); also elsewhere on the board
GPIO_PB1: U1.39 (PB1); also elsewhere on the board
GPIO_PC10: U1.58 (PC10); also elsewhere on the board
GPIO_PC11: U1.59 (PC11); also elsewhere on the board
I2C3_SCL: R7.2, U1.9 (PC0); also elsewhere on the board
I2C3_SDA: R8.2, U1.10 (PC1); also elsewhere on the board
unnamed: D4.1 (K), R24.2
unnamed: Q1.3 (D), R24.1
PP1800_ALW: C4.1, C5.1, C6.1, C7.1, C8.1, C12.1, C13.1, C14.1, C15.1, C19.1, C21.1, C28.1, R4.1, R7.1, R8.1, R26.1, U1.1 (VBAT), U1.30 (VDD), U1.33 (VDDRF), U1.41 (VFBSMPS), U1.43 (VLXSMPS), U1.44 (VDDSMPS), U1.45 (VDD), U1.68 (VDD), U3.A1 (VCC); also elsewhere on the board
PP3300_VDDUSB: C9.1, TP8.1, U1.55 (VDDUSB); also elsewhere on the board
PPVAR_ADC: C16.1, C17.1, R26.2, U1.14 (VDDA); also elsewhere on the board
PPVAR_VIN: D4.2 (A); also elsewhere on the board
RESETB: C10.1, U1.8 (NRST); also elsewhere on the board
SPI2_CLK_PB13: U1.47 (PB13); also elsewhere on the board
SPI2_DEV_CS_L_PB12: U1.46 (PB12); also elsewhere on the board
SPI2_DEV_DC_PC6: U1.50 (PC6); also elsewhere on the board
SPI2_DEV_DO_STM_DI_PB14: U1.48 (PB14); also elsewhere on the board
SPI2_STM_DO_DEV_DI_PB15: U1.49 (PB15); also elsewhere on the board
STM_BOOT0: R5.1, U1.5 (PH3); also elsewhere on the board
STM_LPUART_RXD_PB10: U1.28 (PB10); also elsewhere on the board
STM_LPUART_TXD_PA2: U1.17 (PA2); also elsewhere on the board
STM_SAI1_FS_A: U1.24 (PA9); also elsewhere on the board
STM_SAI1_SCK_A: U1.23 (PA8); also elsewhere on the board
STM_SAI1_SD_A: U1.12 (PC3); also elsewhere on the board
STM_WKUP2_PC13: U1.2 (PC13); also elsewhere on the board
SWD_CLK: U1.56 (PA14); also elsewhere on the board
SWD_IO: U1.54 (PA13); also elsewhere on the board
SWD_O: U1.60 (PC12); also elsewhere on the board
USB_D_N: U1.52 (PA11); also elsewhere on the board
USB_D_P: U1.53 (PA12); also elsewhere on the board
VIN_SNS_ADC1_IN9: C1.1, U1.19 (PA4); also elsewhere on the board
VIN_SNS_EN: U1.65 (PB5); also elsewhere on the board

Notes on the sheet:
BT CONNECTION LED
QSPI MEMORY
BYPASS CAPS
7PF
VDDUSB
Blue
VDD
VFB/VLX/VDDSMPS
VDDRF

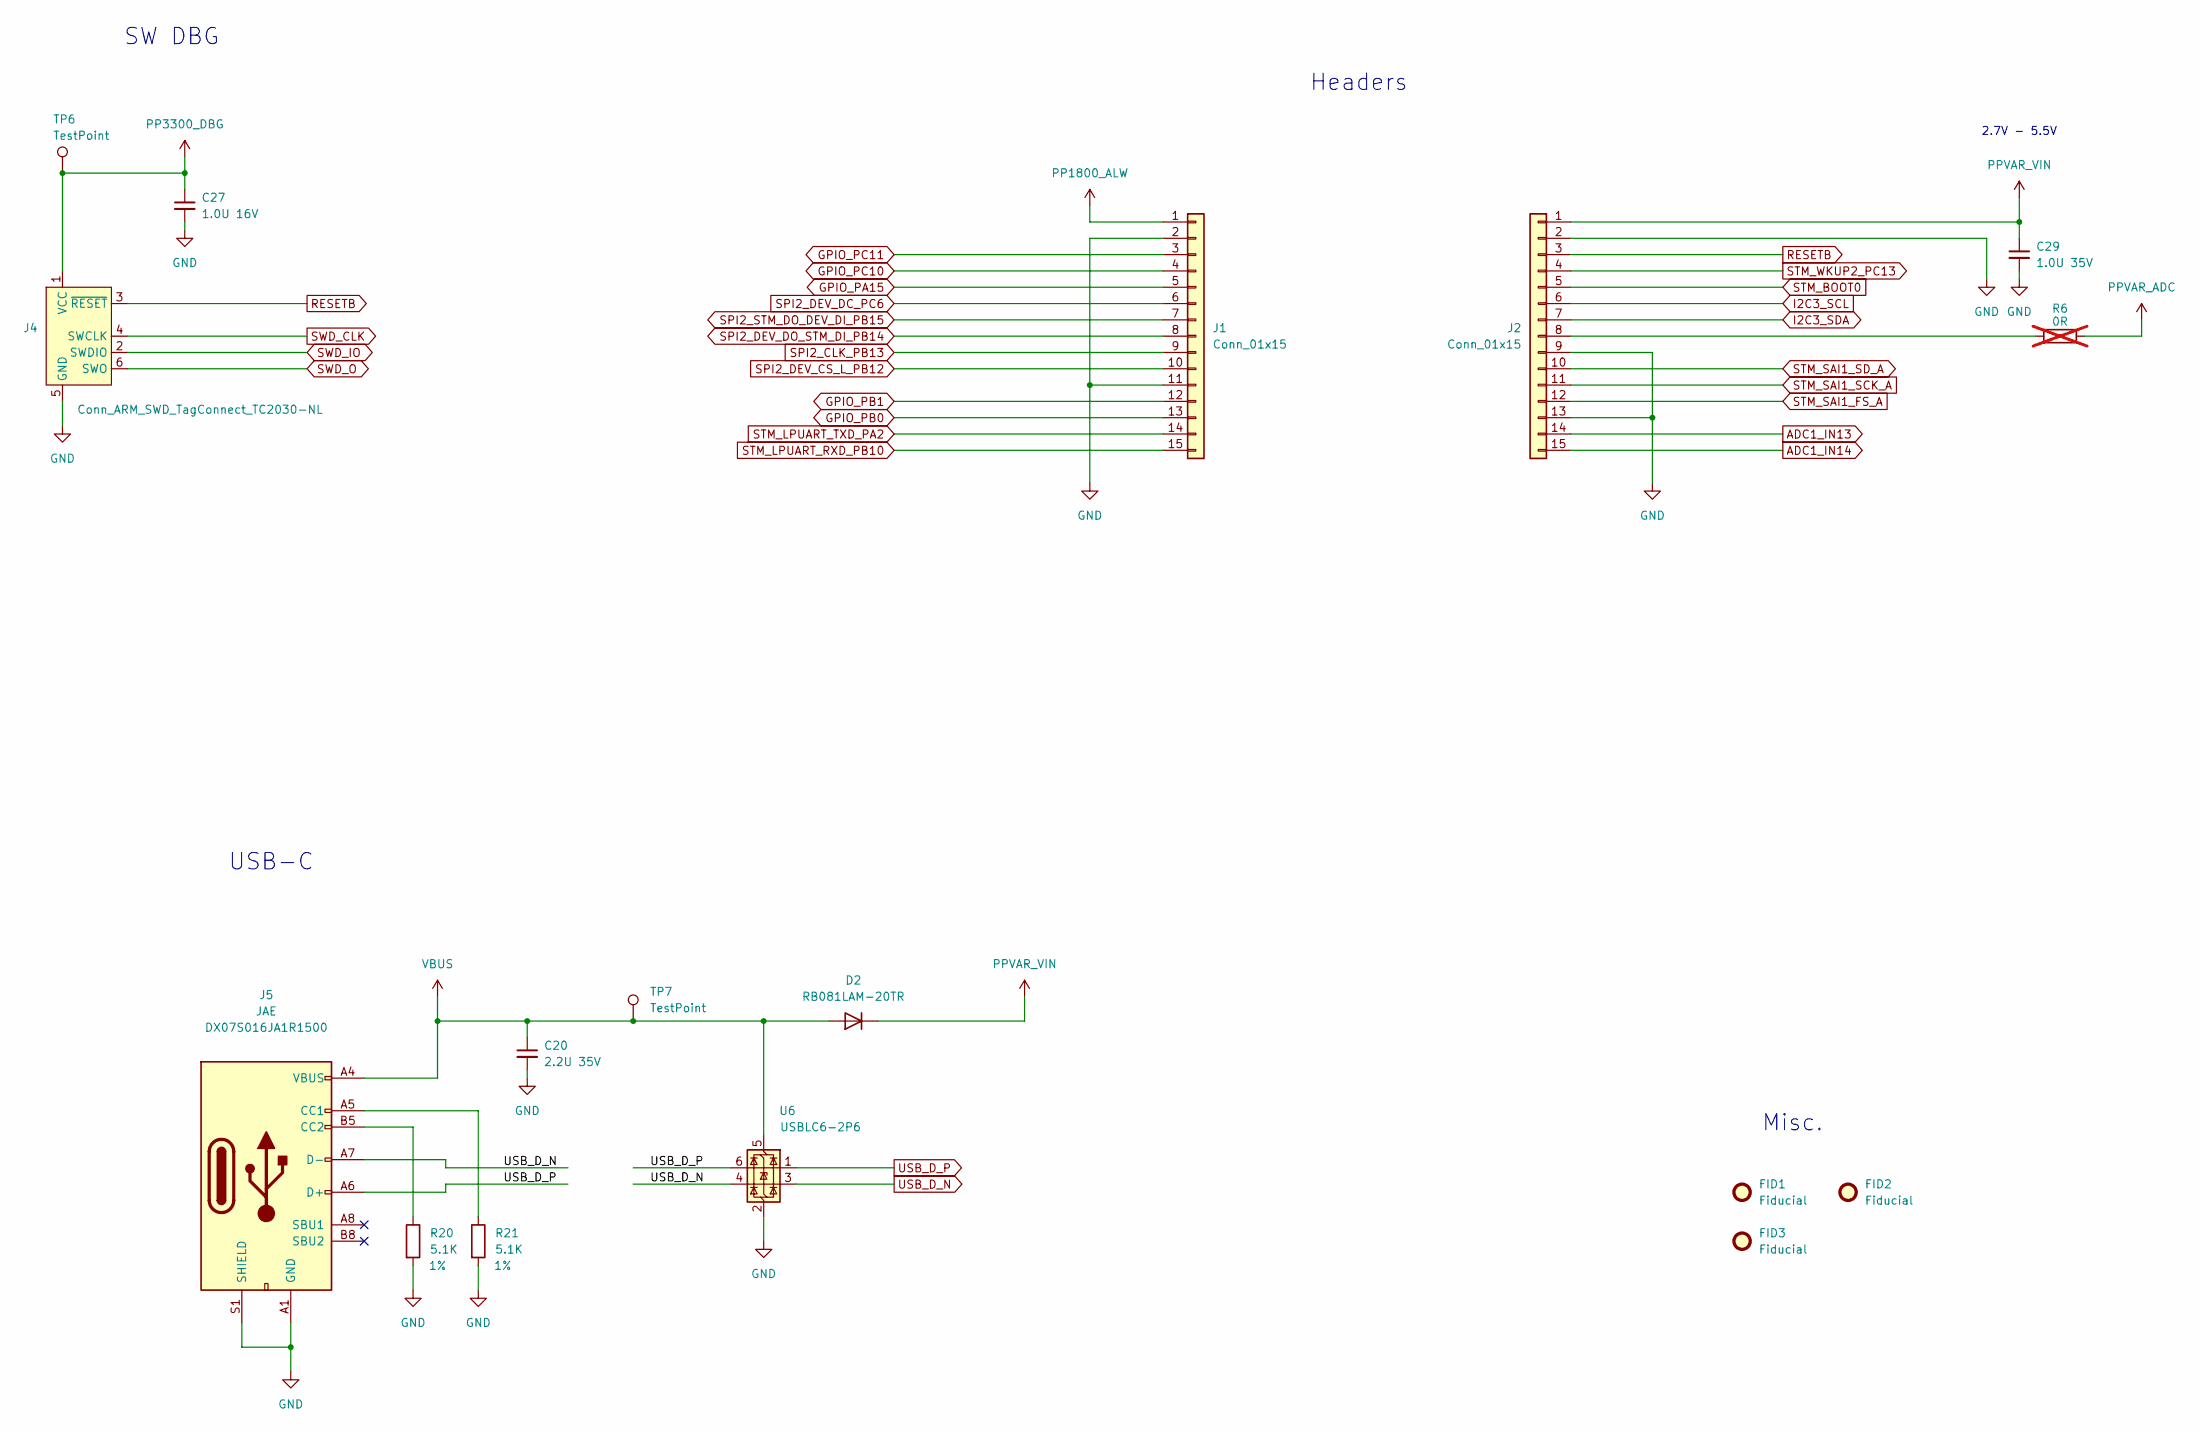
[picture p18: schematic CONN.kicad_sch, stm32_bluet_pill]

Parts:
C20: 2.2U 35V; C_0603_1608Metric
C27: 1.0U 16V; C_0402_1005Metric
C29: 1.0U 35V; C_0603_1608Metric
D2: RB081LAM-20TR; D_SOD-128
FID1, FID2, FID3: Fiducial; Fiducial_0.5mm_Mask1mm
J1, J2: Conn_01x15; PinHeader_1x15_P1.27mm_Vertical
J4: Conn_ARM_SWD_TagConnect_TC2030-NL; Tag-Connect_TC2030-IDC-NL_2x03_P1.27mm_Vertical
J5: DX07S016JA1R1500; USB_C_Receptacle_JAE_DX07S016JA1R1500; MFG_PN DX07S016JA1R1500
R6: 0R; R_0402_1005Metric; not fitted
R20, R21: 5.1K; R_0201_0603Metric
TP6, TP7: TestPoint; TestPoint_Pad_D1.0mm
U6: USBLC6-2P6; SOT-666

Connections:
ADC1_IN13: J2.14; also elsewhere on the board
ADC1_IN14: J2.15; also elsewhere on the board
GND: C20.2, C27.2, C29.2, J1.2, J1.11, J2.2, J2.9, J2.13, J4.5 (GND), J5.A1 (GND), J5.A12 (GND), J5.B1 (GND), J5.B12 (GND), J5.S1 (SHIELD), R20.2, R21.2, U6.2 (GND); also elsewhere on the board
GPIO_PA15: J1.5; also elsewhere on the board
GPIO_PB0: J1.13; also elsewhere on the board
GPIO_PB1: J1.12; also elsewhere on the board
GPIO_PC10: J1.4; also elsewhere on the board
GPIO_PC11: J1.3; also elsewhere on the board
I2C3_SCL: J2.6; also elsewhere on the board
I2C3_SDA: J2.7; also elsewhere on the board
unnamed: J2.8, R6.2
unnamed: J5.A5 (CC1), R21.1
unnamed: J5.B5 (CC2), R20.1
PP1800_ALW: J1.1; also elsewhere on the board
PP3300_DBG: C27.1, J4.1 (VCC), TP6.1; also elsewhere on the board
PPVAR_ADC: R6.1; also elsewhere on the board
PPVAR_VIN: C29.1, D2.1 (K), J2.1; also elsewhere on the board
RESETB: J2.3, J4.3 (~RESET); also elsewhere on the board
SPI2_CLK_PB13: J1.9; also elsewhere on the board
SPI2_DEV_CS_L_PB12: J1.10; also elsewhere on the board
SPI2_DEV_DC_PC6: J1.6; also elsewhere on the board
SPI2_DEV_DO_STM_DI_PB14: J1.8; also elsewhere on the board
SPI2_STM_DO_DEV_DI_PB15: J1.7; also elsewhere on the board
STM_BOOT0: J2.5; also elsewhere on the board
STM_LPUART_RXD_PB10: J1.15; also elsewhere on the board
STM_LPUART_TXD_PA2: J1.14; also elsewhere on the board
STM_SAI1_FS_A: J2.12; also elsewhere on the board
STM_SAI1_SCK_A: J2.11; also elsewhere on the board
STM_SAI1_SD_A: J2.10; also elsewhere on the board
STM_WKUP2_PC13: J2.4; also elsewhere on the board
SWD_CLK: J4.4 (SWCLK); also elsewhere on the board
SWD_IO: J4.2 (SWDIO); also elsewhere on the board
SWD_O: J4.6 (SWO); also elsewhere on the board
USB_D_N: J5.A7 (D-), J5.B7 (D-), U6.3 (I/O2), U6.4 (I/O2); also elsewhere on the board
USB_D_P: J5.A6 (D+), J5.B6 (D+), U6.1 (I/O1), U6.6 (I/O1); also elsewhere on the board
VBUS: C20.1, D2.2 (A), J5.A4 (VBUS), J5.A9 (VBUS), J5.B4 (VBUS), J5.B9 (VBUS), TP7.1, U6.5 (VBUS); also elsewhere on the board

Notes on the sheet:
Headers
USB-C
Misc.
SW DBG
2.7V - 5.5V

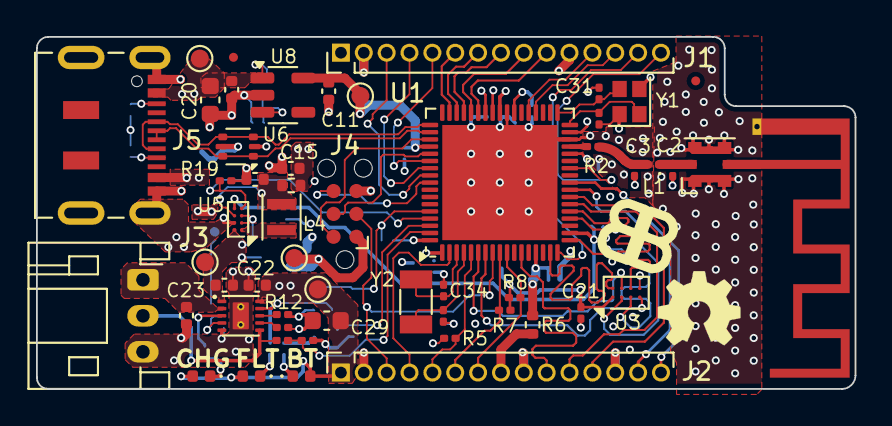
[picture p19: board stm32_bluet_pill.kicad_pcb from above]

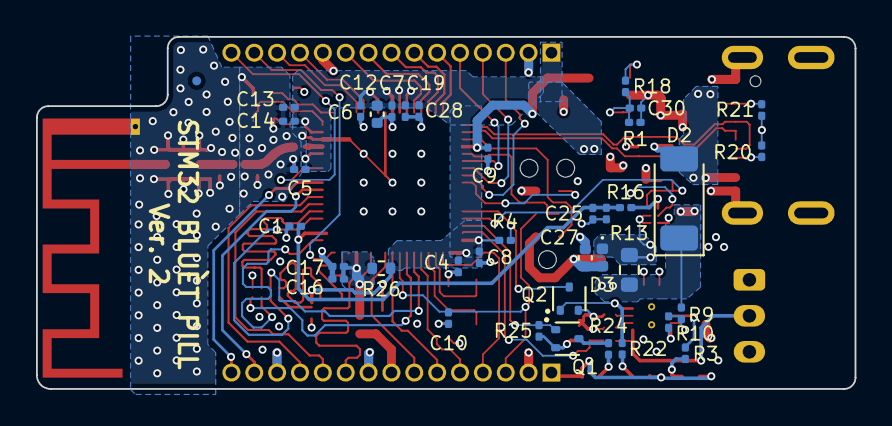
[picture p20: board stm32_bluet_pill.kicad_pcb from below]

Board: 4 copper layers, 45.5 x 19.6 mm, 92 parts (38 on the bottom side), 72 nets.

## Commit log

2024-04-03 Add initial project files.
    [BATTERY_CHARGER.kicad_sch, Bluetooth_OSHW.kicad_pcb, Bluetooth_OSHW.kicad_sch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]
2024-04-04 Adding outputs, updated some component values.
    [Bluetooth_OSHW-B_Cu.gbr, Bluetooth_OSHW-B_Mask.gbr, Bluetooth_OSHW-B_Paste.gbr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]
2024-04-04 removed backup zips. adding updated output files
    [Bluetooth_OSHW-B_Cu.gbr, Bluetooth_OSHW-B_Mask.gbr, Bluetooth_OSHW-B_Paste.gbr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]
2024-04-06 updating design files
    updating schematics, gerbers, design files, etc.
    [Bluetooth_OSHW-B_Cu.gbr, Bluetooth_OSHW-B_Mask.gbr, Bluetooth_OSHW-B_Paste.gbr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]
2024-04-06 Update stm32_bluet_pill-block-diagram.png
    reduced the size of the block diagram
2024-04-16 renamed all 'Bluetooth_OSHW' files.
    renamed files to stm_32_bluet_pill to keep consistency with the public git repo name.
    [Bluetooth_OSHW.kicad_pcb, Bluetooth_OSHW.kicad_sch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]
2024-04-18 Updated project
    - Changed board stackup, trace-widths
    - Changed VIA size
    - Fixed fab drawings
    - added CHG FLT LED
    - Removed unnecessary files
    [CONN.kicad_sch, MCU_BLE.kicad_sch, POWER.kicad_sch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]
2024-04-18 Update stm32_bluet_pill.png
    cropped main image
2024-12-03 Various BOM and Bug Fixes * Changed Stackup to common JLCPCB stackup * Modified trace widths as per new stackup * Reduced drill hole size * Rotated uFL connector as per datasheet pinout * Added pop o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
    [CONN.kicad_sch, MCU_BLE.kicad_sch, POWER.kicad_sch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]
